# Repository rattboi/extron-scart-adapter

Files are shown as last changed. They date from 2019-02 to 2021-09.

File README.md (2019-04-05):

Extron Scart Adapter projects
=============================

Extron Input Adapter
--------------------

[Extron-Input README](extron-input/README.md)

This board should plug into an extron crosspoint input, and has the following features:

1) Female Scart input
1) JST header to Phoenix adapter (cheap)
1) Sense header to determine if connected cable is "active"
1) Selectable LM1881 Sync Stripper for sync on composite video / sync on luma

Extron Output Adapter
--------------------

[Extron-Output README](extron-output/README.md)

This board should plug into an extron crosspoint output, and has the following features:

1) Female Scart output
1) JST header to Phoenix adapter (cheap)
1) Selectable termination resistor for 75 ohm or TTL level sync output

Extron SCART Autoswitcher
-------------------------

[Autoswitcher README](esp32-switcher/README.md)

This board plugs into the serial port on an Extron crosspoint, and works together with the input cards to determine which input has be most-recently powered on, and automatically switches to that input.

Simple Scart Adapter (DEPRECATED)
---------------------------------

This board was my first attempt, and it turned out to not be workable. I'm leaving it for posterity, but you shouldn't use it.
The spacing is way off for a Crosspoint. I based the measurements on an Extron System 5CR Plus, which has narrower spacing between BNC connectors.

License
-------

These projects are licensed under CERN Open Hardware Licence v1.2

This is a work-in-progress as well, as I believe I'm missing the attribution on the boards. My intent is to license them properly.

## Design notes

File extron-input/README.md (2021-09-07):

Extron SCART Input adapter
==========================

The Extron SCART Input adapters are designed to be inserted into an Extron Crosspoint input vertically, using BNC->RCA male adapters to mate with the adapter card's RCA female jacks. There are two supported BNC spacings, one that is looser (older Extrons) and one that is tighter (newer Extrons). When you assemble your card, you use the correct RCA spacing to support your Extron. The looser spacing is labeled RED1/GREEN/BLUE1/SYNC1, while the tighter spacing is labeled RED2/GREEN/BLUE2/SYNC2. You'll notice that GREEN is shared between the two spacings.

Below, you will notice that there is a design for a 'top' card and a 'bottom' card. This was required in order to get the cards close enough together horizontally (from the perspective of the Extron). The SCART heads are large and for the newer Extron spacing, the BNC spacing is just too tight to have the SCART heads stack. Therefore, you should plan to make both 'top' and 'bottom' cards, and alternate them. I use plastic standoffs to group 3-4 boards together. For the newer Extrons, I found that alternating 15mm and 16mm standoffs gave a perfect fit. Anothe alternative would be to just pair up a top and bottom board, and use either 15mm or 16mm. The error builds when you try to create a larger matrix, so you shouldn't have any problem if you make smaller matrices.

Features
========

The Extron input cards have optional sync strippers that are togglable via a switch that is labeled on the PCB. The lm1881 sync stripper is powered by the SCART cable's pin 8 (switch pin). The SCART standard says that this should be carrying 5v-12v. Anywhere in that range works fine to power the lm1881.

Also, there is a small custom circuit to determine if the console is powered on, via the switch pin on the SCART connector. This can be paired with the [autoswitcher](../esp32-switcher) to automatically switch the extron input to match the last powered-on device. This circuit takes 5-12V and lowers it down to 2.5-3.3V, which is low enough to be a simple digital 'on' signal to the [autoswitcher](../esp32-switcher) board.

PCB Renders
===========

## Front

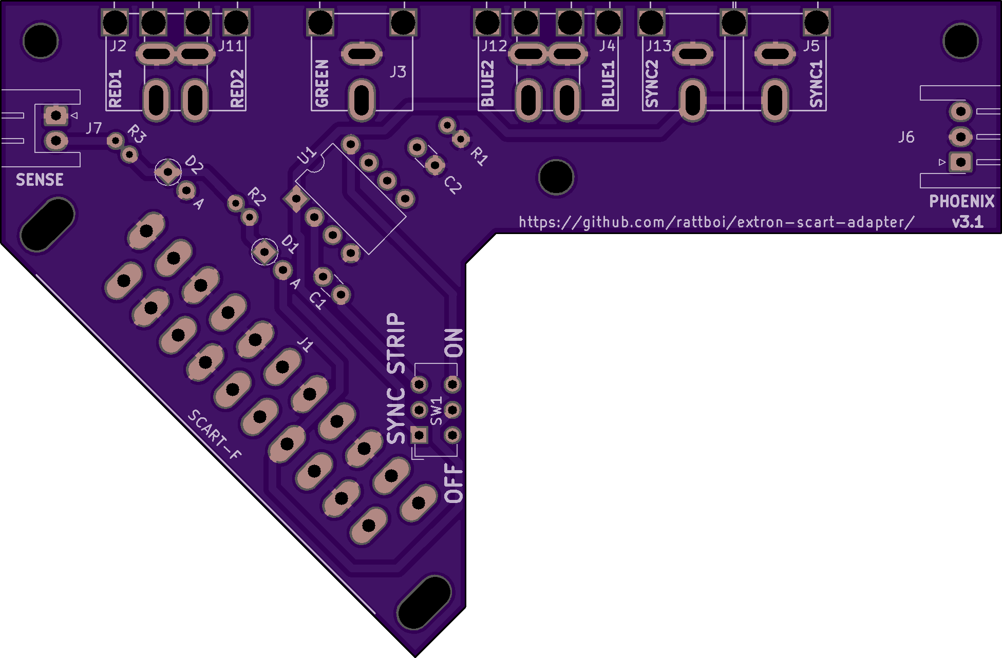
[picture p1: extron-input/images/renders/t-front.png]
Front Render

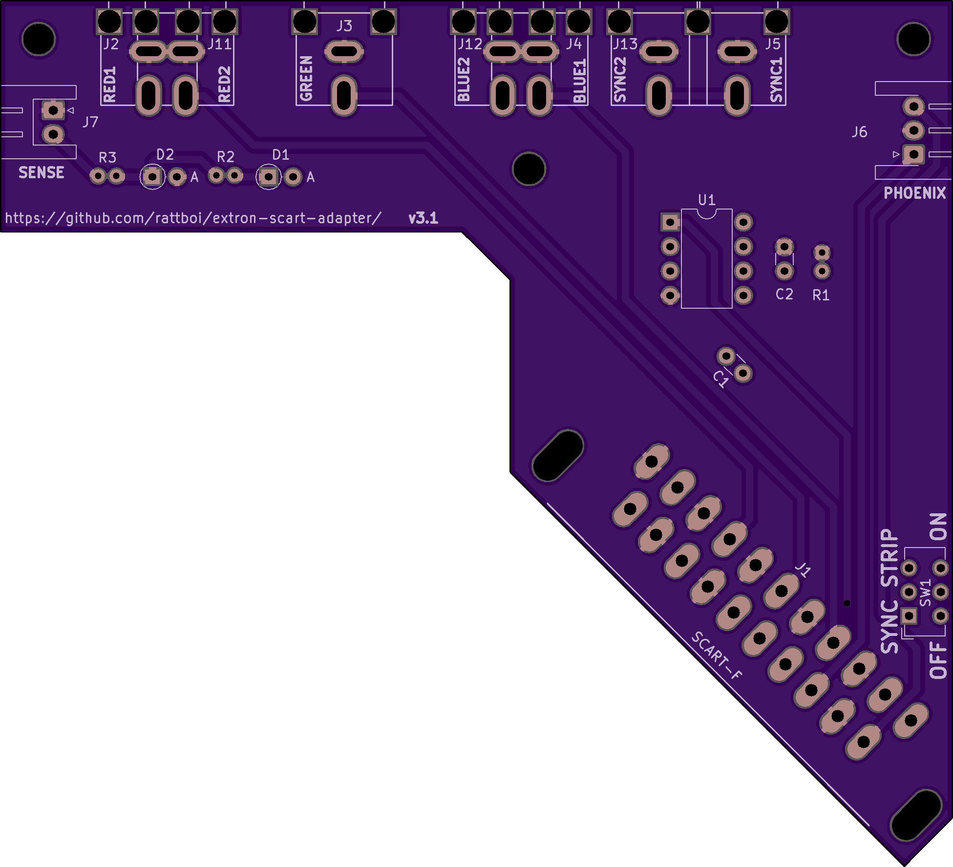
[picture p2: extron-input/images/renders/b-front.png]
Front Render


## Back

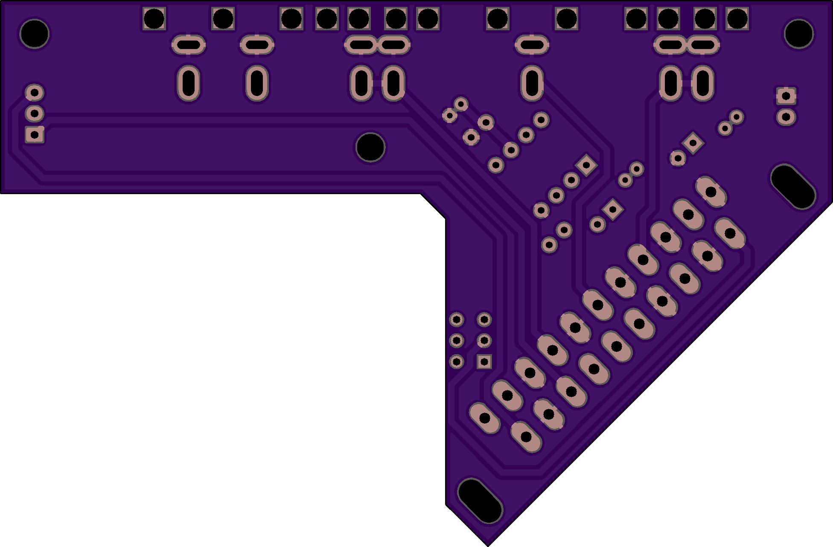
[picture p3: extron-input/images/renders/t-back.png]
Back Render

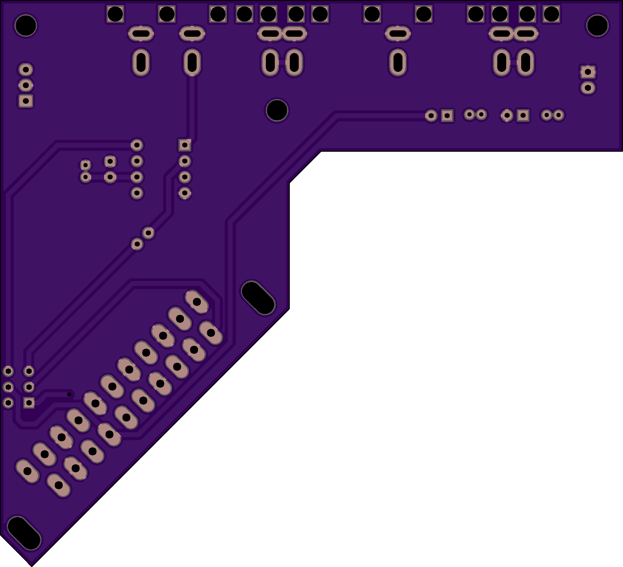
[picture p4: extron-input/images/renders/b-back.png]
Back Render


3D Renders
==========

## Top

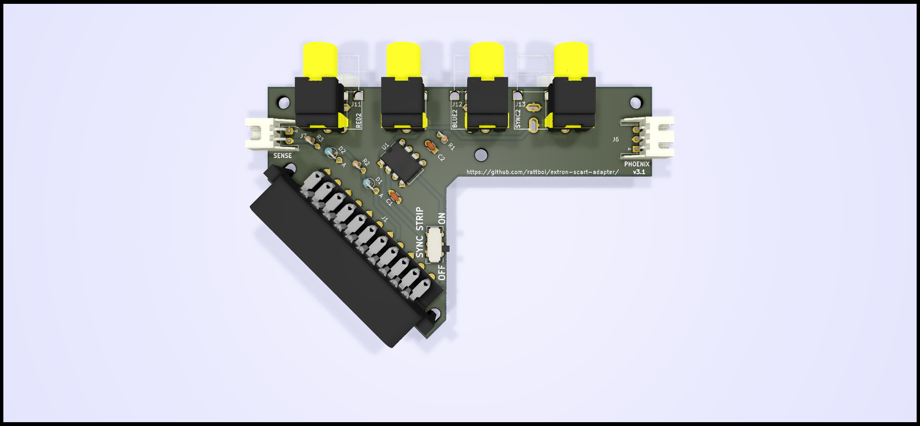
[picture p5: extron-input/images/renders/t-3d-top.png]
Top Render

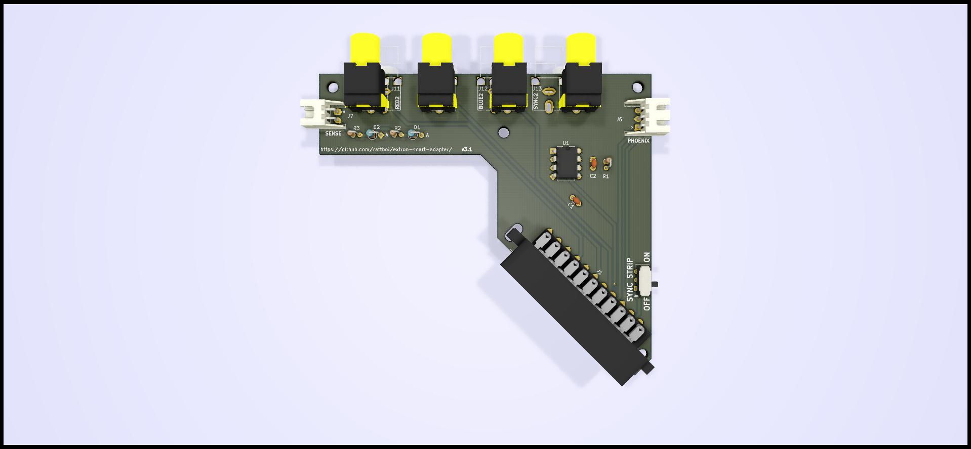
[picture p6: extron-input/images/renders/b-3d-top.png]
Top Render


## Front

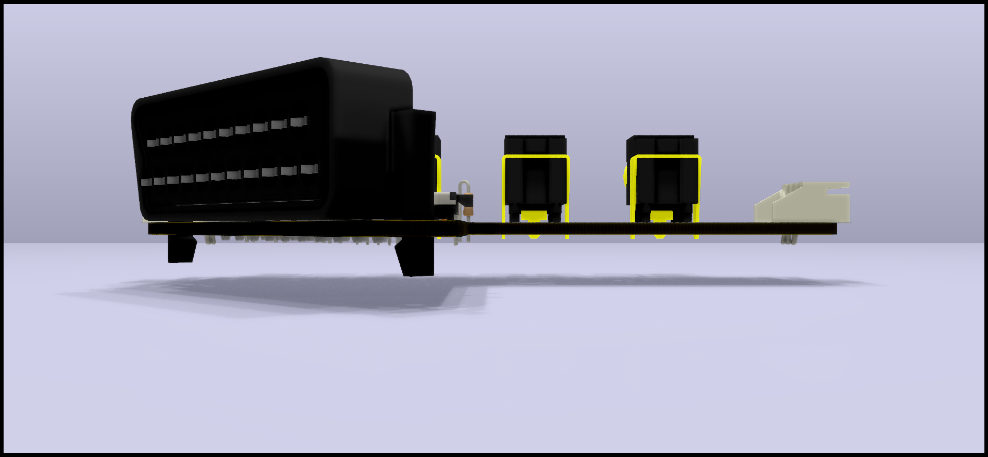
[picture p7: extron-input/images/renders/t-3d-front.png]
Front Render

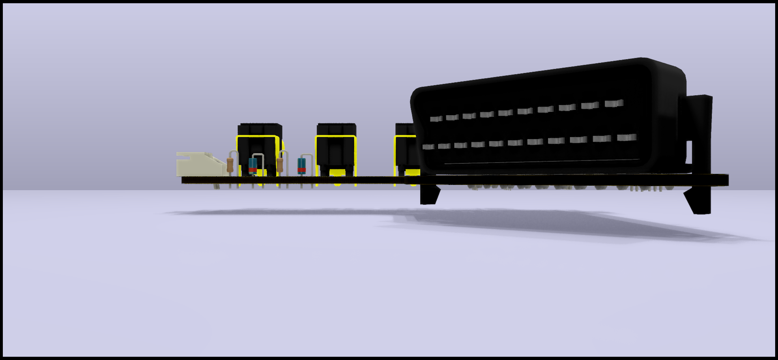
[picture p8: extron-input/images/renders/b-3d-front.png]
Front Render


## Side

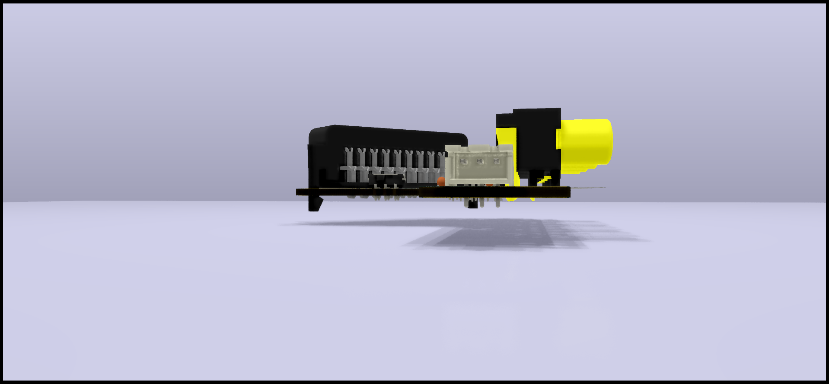
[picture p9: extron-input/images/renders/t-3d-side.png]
Side Render

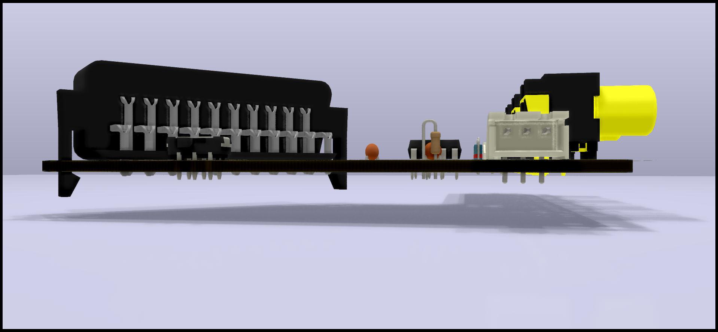
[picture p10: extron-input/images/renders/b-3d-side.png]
Side Render


Assembled Cards
===============

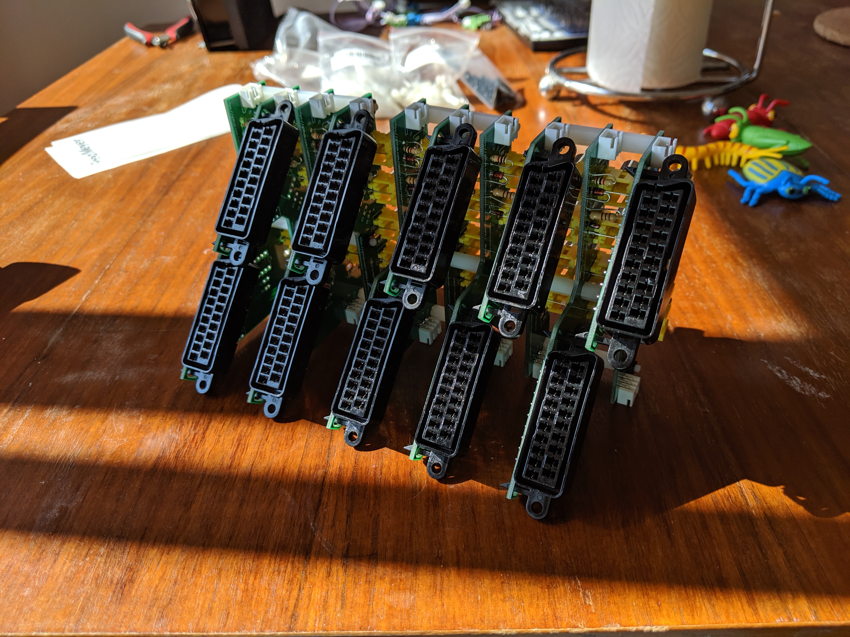
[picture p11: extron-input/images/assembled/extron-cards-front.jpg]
Front

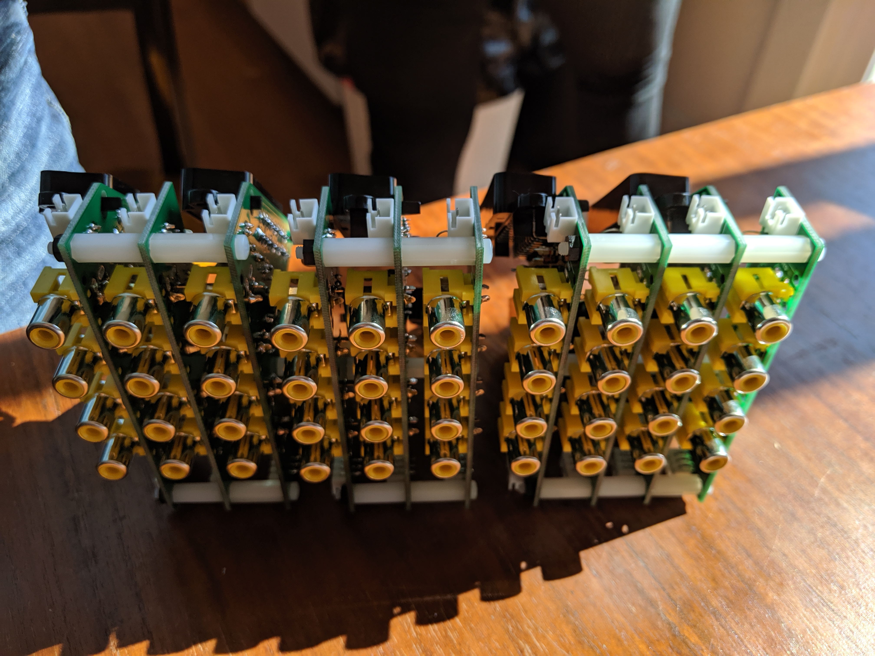
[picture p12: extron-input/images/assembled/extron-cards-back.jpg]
Back

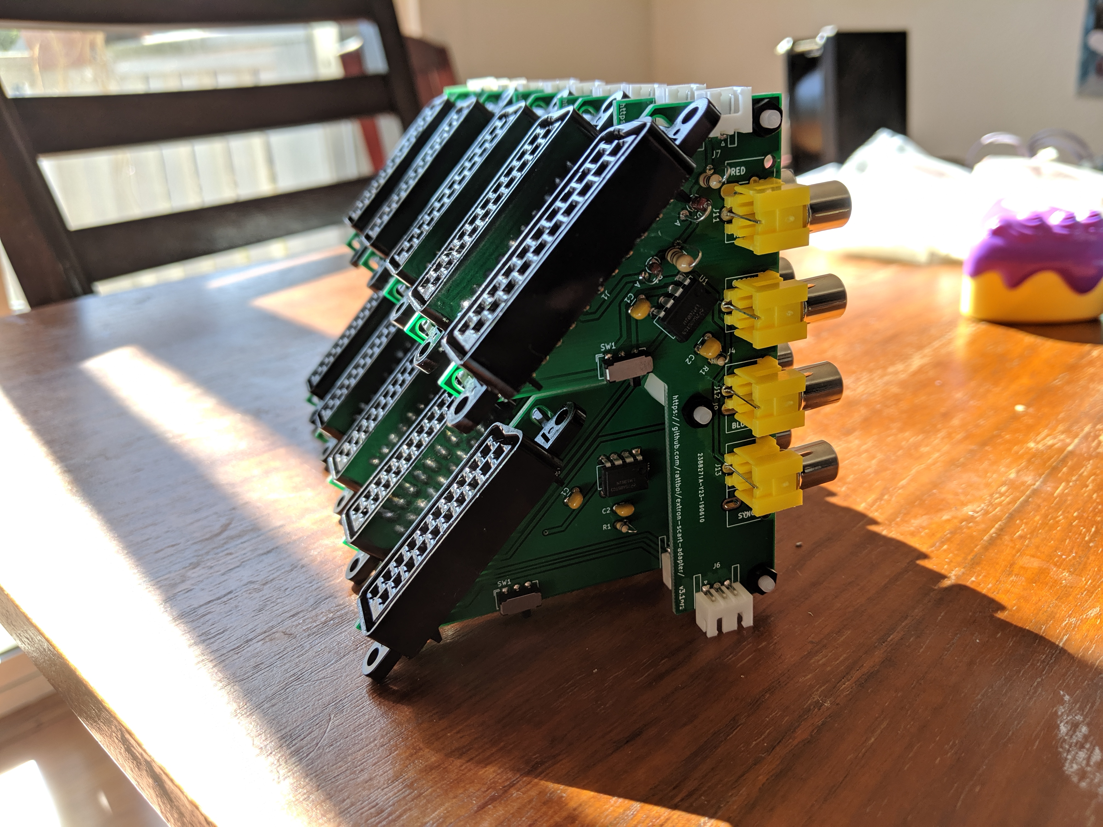
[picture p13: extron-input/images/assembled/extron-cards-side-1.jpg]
Side 1

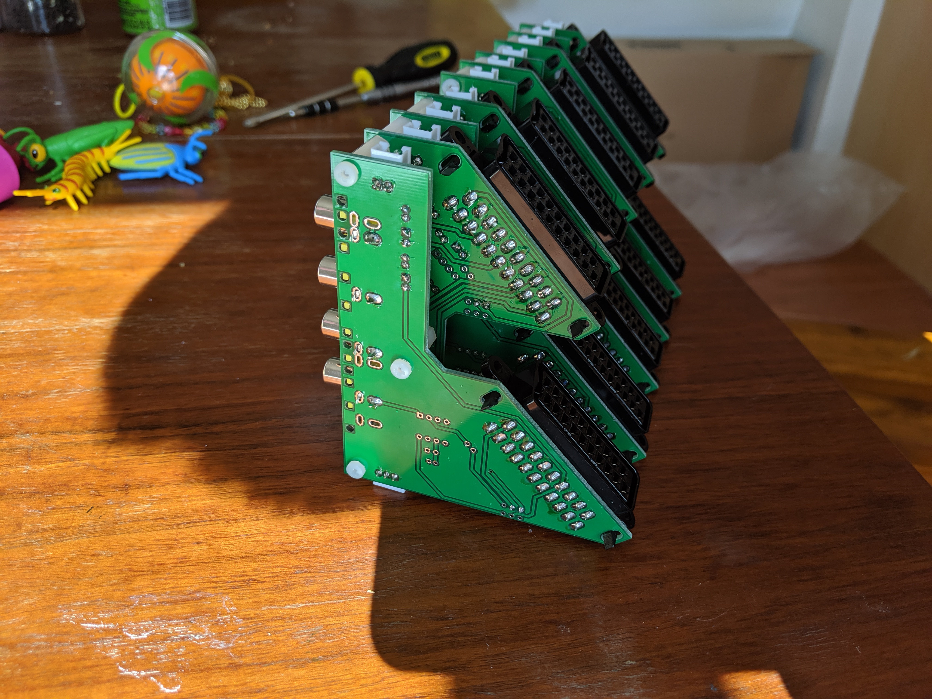
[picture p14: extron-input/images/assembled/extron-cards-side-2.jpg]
Side 2


Others
======

Back of Extron, prepared for cards
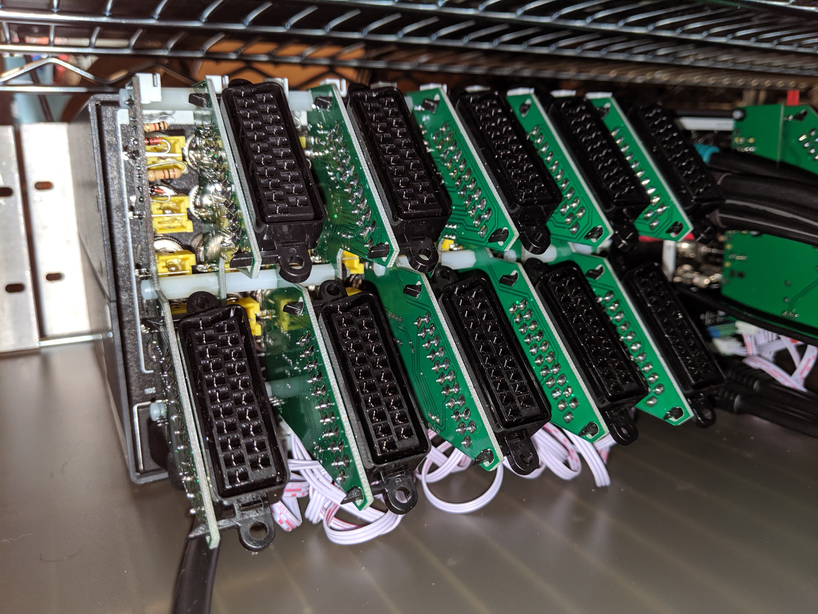
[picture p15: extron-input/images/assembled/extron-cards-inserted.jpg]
Cards inserted, no SCART cables

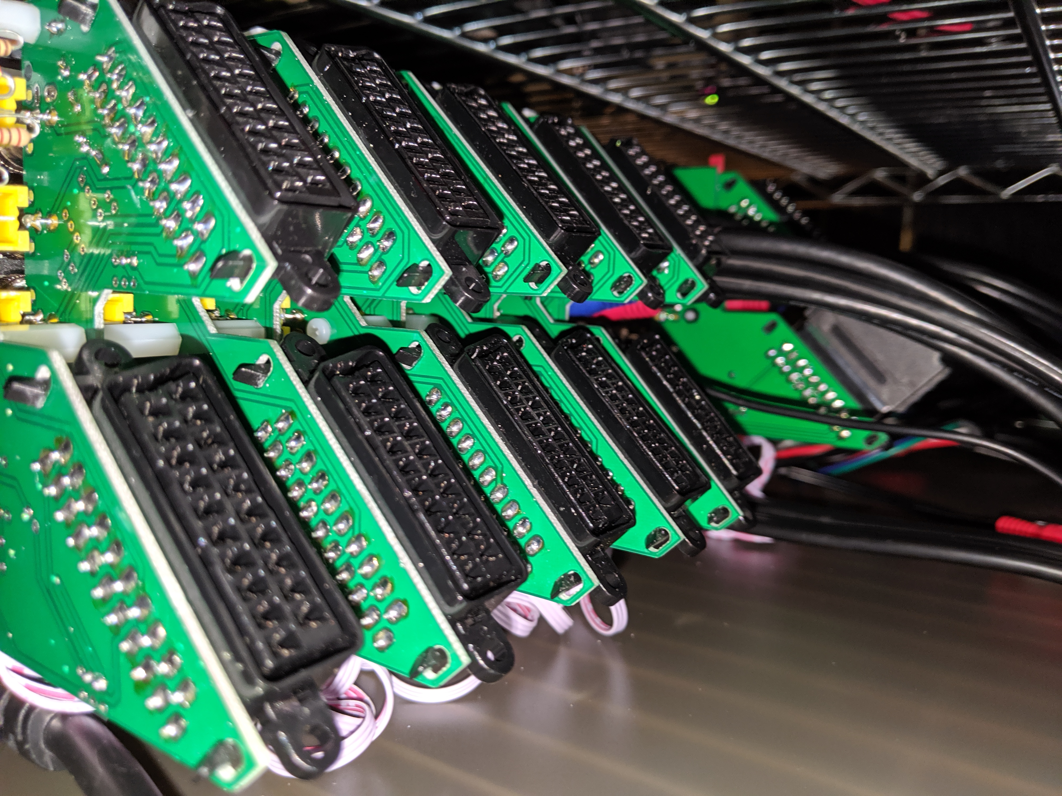
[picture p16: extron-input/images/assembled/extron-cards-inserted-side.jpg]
Cards inserted, no SCART cables (side)

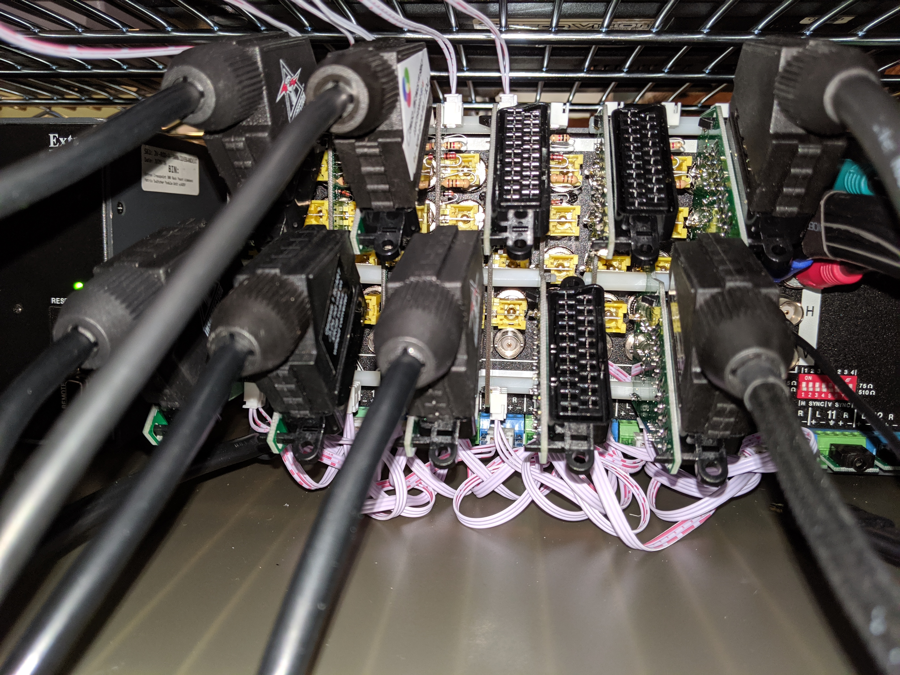
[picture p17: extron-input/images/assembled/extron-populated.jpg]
Cards inserted, with SCART cables


BOM
===========
| Item | Qty | Reference(s) | Value | Footprint | Datasheet |
|---|-----|---|---|---|---|
| 1 | 2 | C1, C2 | 0.1uF | Capacitor_THT:C_Disc_D3.0mm W1.6mm_P2.50mm | https://lcsc.com/product-detail/Multilayer-Ceramic-Capacitors-MLCC-Leaded_100nF-104-20-100V_C154503.html |
| 2 | 1 | D1 | 1N4148 | Diode_THT:D_DO-35_SOD27 P2.54mm_Vertical_AnodeUp | https://lcsc.com/product-detail/Switching-Diode_1N4148_C14516.html |
| 3 | 1 | D2 | 1N4728A | Diode_THT:D_DO-35_SOD27 P2.54mm_Vertical_AnodeUp,~ | https://lcsc.com/product-detail/Zener-Diodes_ON-Semicon_1N4728A_ON-Semicon-ON-1N4728A_C140852.html |
| 4 | 1 | J1 | SCART-F | extron-input:SCART_F_RA, ~ | https://console5.com/store/female-scart-jp21-through-hole-pcb-mount-21-pin-connector-right-angle.html |
| 5 | 1 | J2/J11 | RED | extron-input:rca_boom, ~ | https://lcsc.com/product-detail/AV-Connectors_AV-5_C18080.html |
| 6 | 1 | J3 | GREEN | extron-input:rca_boom, ~ | https://lcsc.com/product-detail/AV-Connectors_AV-5_C18080.html |
| 7 | 1 | J4/J12 | BLUE | extron-input:rca_boom, ~ | https://lcsc.com/product-detail/AV-Connectors_AV-5_C18080.html |
| 8 | 1 | J5/J13 | SYNC | extron-input:rca_boom, ~ | https://lcsc.com/product-detail/AV-Connectors_AV-5_C18080.html |
| 9 | 1 | J6 | PHOENIX | Connector_JST:JST_XH_S03B XH-A_1x03_P2.50mm_Horizontal,~ | https://lcsc.com/product-detail/XH-Connectors_JST_S3B-XH-A-LF-SN_XHsocket-1-3P-Curved-needle-pitch2-5mm_C157928.html |
| 10 | 1 | J7 | SENSE | Connector_JST:JST_XH_S02B XH-A_1x02_P2.50mm_Horizontal,~ | https://lcsc.com/product-detail/XH-Connectors_JST_S2B-XH-A-LF-SN_XHsocket-1-2P-Curved-needle-pitch2-5mm_C157931.html |
| 11 | 4 | J8, J9, J10, J11 | Conn_01x01 | MountingHole:MountingHole_3.2mm_M3 | N/A |
| 12 | 1 | R1 | 680KΩ | Resistor_THT:R_Axial_DIN0204 L3.6mm_D1.6mm_P1.90mm_Vertical | https://lcsc.com/product-detail/Others_FlyWin-CR1-8W-5-680K-OTB5_C337028.html |
| 13 | 1 | R2 | 100Ω | Resistor_THT:R_Axial_DIN0204 L3.6mm_D1.6mm_P1.90mm_Vertical | https://www.lcsc.com/product-detail/Through-Hole-Resistors_CCO-Chian-Chia-Elec-CF1-4W-100-5-T52_C120031.html |
| 14 | 1 | R3 | 1KΩ | Resistor_THT:R_Axial_DIN0204 L3.6mm_D1.6mm_P1.90mm_Vertical | https://lcsc.com/product-detail/Carbon-Film-Resistors_1KR-102-5_C120055.html |
| 15 | 1 | SW1 | SW_DPDT_x2 | Button_Switch_THT:SW_CuK JS202011AQN_DPDT_Angled, | https://lcsc.com/product-detail/Toggle-Switches_C-K_JS202011AQN_C-K-JS202011AQN_C221662.html |
| 16 | 1 | U1 | LM1881 | Package_DIP:DIP-8_W7.62mm, | https://www.ti.com/store/ti/en/p/product/?p=LM1881N/NOPB

LCSC     Sub-total: __$14.94__ for everything for 10x boards (plus lots of spare parts)

Console5 Sub-total: __$14.90__ for RA Female SCART connectors

TI       Sub-total: __$28.40__ for LM1881n 

BOM Total for 10x boards: __$58.40__ plus Console5/TI shipping

BOM Total with shipping: __~$70__

You'll want 5x of the top boards and 5x of the bottom boards
PCBs: __$4 for 5__ top, __$4 for 5__ bottom, plus $6 for slower shipping = __$14__

Cost for 10 boards, all parts: $70+14 = $84 = __$8.40__ each

Other Supporting Parts 
======================

Phoenix adapter (for audio)
---------------------------

I've respun db_electronics' Phoenix RCA plug board to use JST headers: https://github.com/rattboi/phoenix-audio-adapter-kicad/tree/jst-xh/

$5 for 10x more boards on JLCPCB order, and $0.89 for JST headers

__$5.89__ for 10x populated boards = __$0.59 each__

JST cables (connect input audio to phoenix board)
----------
https://www.amazon.com/gp/product/B07HRMWVK9/

__$8 for 10__(need to find a better source)

BNC M to RCA M Plug Adapters
---------------
https://www.amazon.com/gp/product/B005C2KA88/

$5.39 for 10

__$21.56 for 40__ (4x per board, 10 boards)

Alternative: 

https://www.amazon.com/gp/product/B01H1A4QAQ/

$6.42 for 10

$25.68 for 40

10x board Total
===============
10x board + phoenix + cables + adapters: $84 + $6 + $8 + $22 = __~$120__

__$12 each, all parts, shipped__

10x boards Stripped-down 
------------------------

If you were to remove the optional components (no sync stripper, no sense circuit), you can get the price down further

Removing switch + lm1881 and passives for lm1881 + passives for sense circuit + sense connector: 

LCSC     Sub-total: $7.06

Console5 Sub-total: $14.90 for SCART connectors

BOM Total with shipping: $7.06 + $14.90 + $5 = $27

PCBS are the same, so $14 for 10x boards shipped

The rest of the parts are the same

10x board + phoenix + cables + adapters: $41 + $3 + $8 + $23 = __~$75__

__$7.50 each, stripped-down, shipped__

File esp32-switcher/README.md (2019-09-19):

Extron SCART Autoswitcher
=========================

This board, in conjunction with a HiLetGo ESP-E32 development board, can be used to sense input changes from the Extron Input adapters, and use that information to automatically switch to the most recently turned-on input.

Each input board has a sense port, which you connect to the autoswitch board via a JST XH cable. The board then plugs into your extron either via straight-through M-F serial cable (not null modem), or by directly mounting the board onto the port. The ESP32 also needs external power, which can be supplied by any 5V USB charger that you may have laying around.

PCB
===

3D Renders
==========
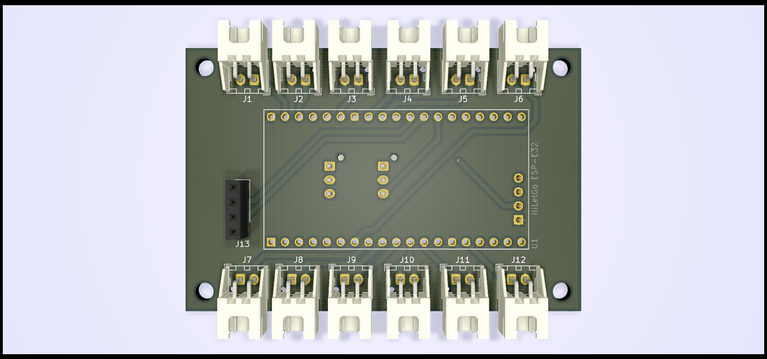
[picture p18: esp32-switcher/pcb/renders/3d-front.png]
Front Render

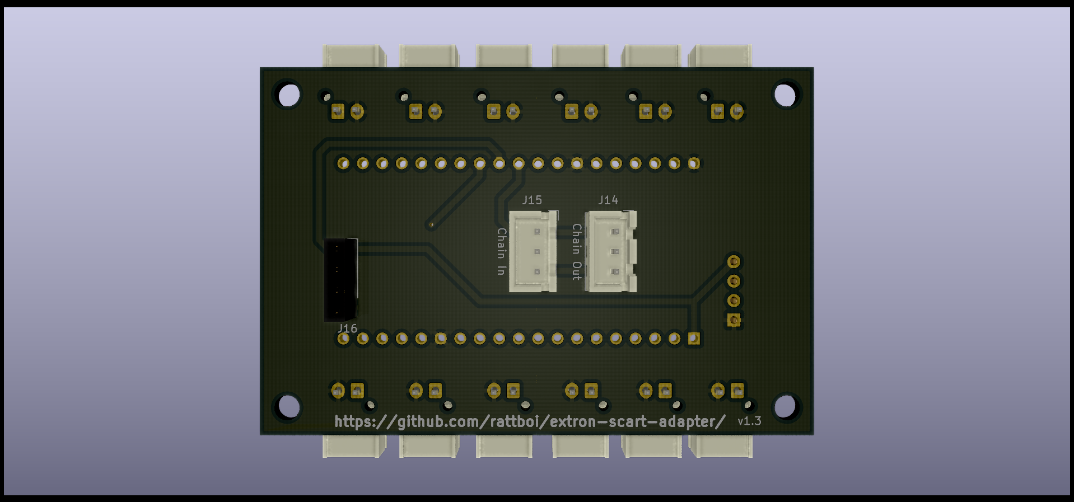
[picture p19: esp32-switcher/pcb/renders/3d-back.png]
Back Render


PCB Renders
===========

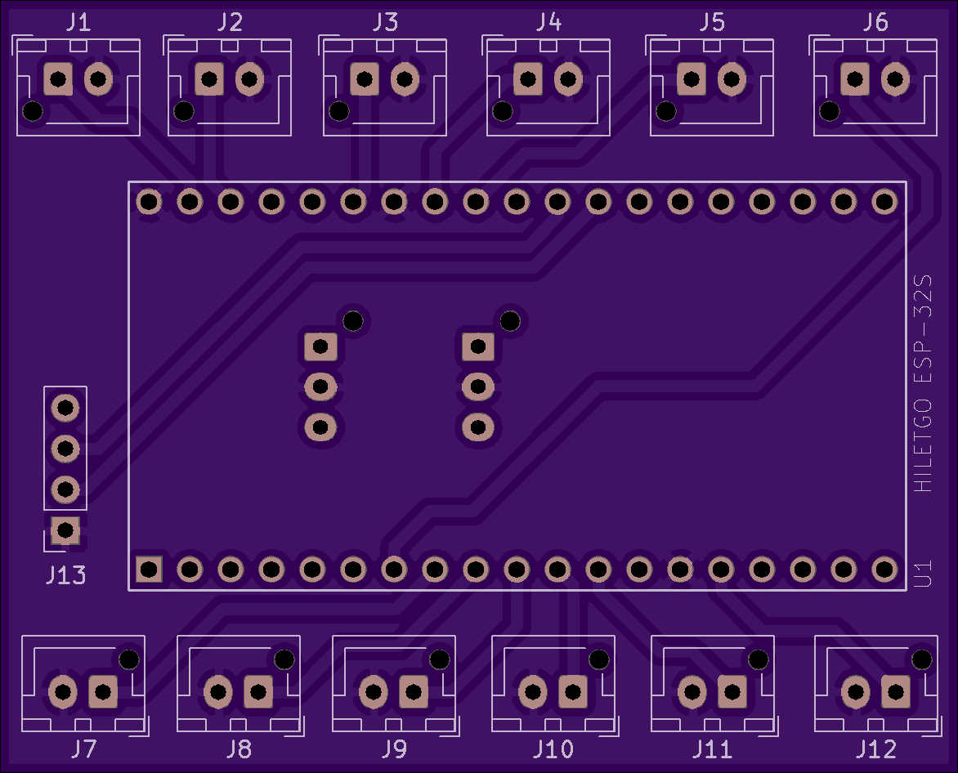
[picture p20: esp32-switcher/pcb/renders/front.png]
Front Render

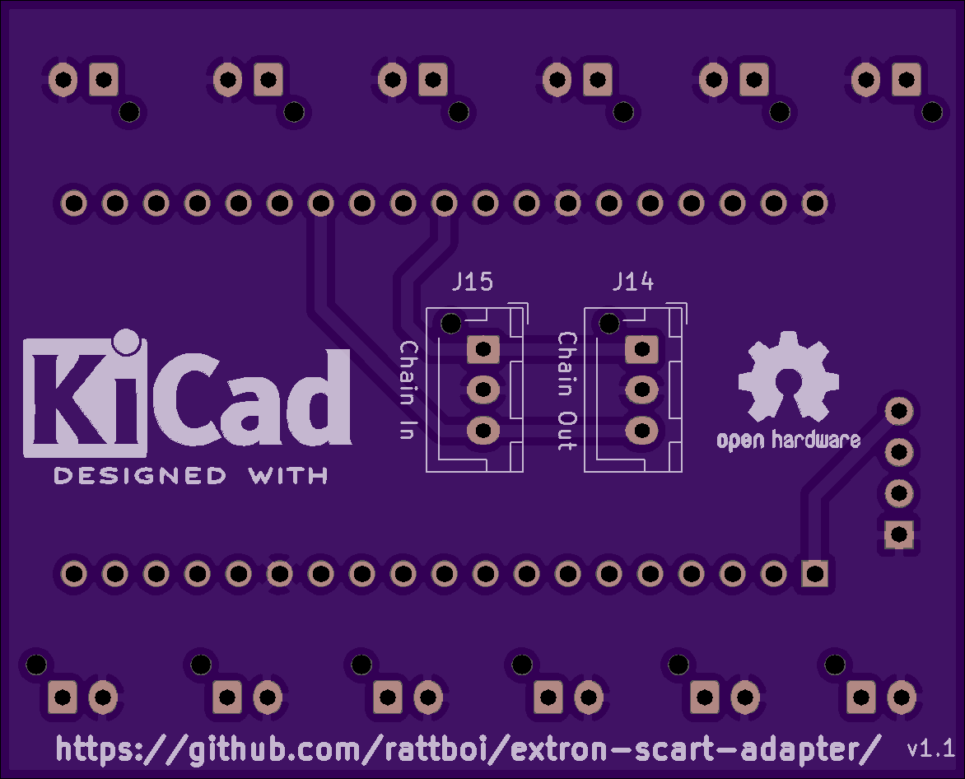
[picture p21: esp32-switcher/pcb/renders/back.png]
Back Render


BOM
===========
| Item  | Qty | Reference(s) | Value | Footprint | Datasheet |
|---|-----|---|---|---|---|
| 1 | 1 | U1 | ESP32 | hiletgo-e32:HILETGO-E32 |  https://www.amazon.com/gp/product/B0718T232Z/ref=ppx_yo_dt_b_search_asin_title?ie=UTF8&psc=1 |
| 2 | 1 | J13/J16 | RS232 | Connector_PinSocket_2.54mm:PinSocket_1x04_P2.54mm_Vertical  |  https://www.amazon.com/gp/product/B00OPU2QJ4/ref=ppx_yo_dt_b_asin_title_o02_s00?ie=UTF8&psc=1 |
| 3 |  14 | J1-12,14,15 | JST-XH RA  | Connector_JST:JST_XH_B2B-XH-AM_1x02_P2.50mm_Vertical | |

Notes:
* You only need one RS232 TTL Converter. There's two spots (J13 or J16) on the board to place it, depending on what orientation you want your switchboard to be.
* You can skip J14/J15 for now. They are WIP to chain together switchboards for cascading multiple Extrons
* If you don't want the ESP32 to be permanently soldered to the switchboard, you can use pin header for the two rows of pins where the ESP32 plugs in.
* I would recommend directly soldering the RS232 in place for stability, but you could use pin header there as well.

Code
====

The code for the autoswitcher is currently in micropython. The basic steps involved are as follows to get the board going.

1) Install any driver you may need for the usb->serial built into the ESP32. This is the CP2102 driver, and necessary for Windows and macOS. Linux comes with this driver pre-installed.

2) Plug the ESP32 into your computer, and find the serial device.
  This is straightforward in Linux/macOS, as it appears as /dev/ttyUSB0 or something close to that. I'm not actually sure what this looks like in windows.

3) Install the following programs to interact with the ESP32: esptool.py and ampy.
  esptool.py will allow you to flash micropython onto your ESP32
  ampy will allow you to move the boot code from this repo onto your ESP32 to be executed by micropython

4) Install micropython, some current revision.
  I'm not going to go through all the steps for this, but on Linux it looks something like `sudo esptool --chip esp32 -p /dev/ttyUSB0 write_flash -z 0x1000 ~/Downloads/esp32-20190328-v1.10-243-g92149c8a7.bin`
  `
5) Move the boot code over after micropython is installed
  `ampy -p /dev/ttyUSB0 put code/boot.py`

You're done now. Plug everything in. J1 -> Input 1, J2 -> Input 2, etc.

Congrats, now you have autoswitching power!

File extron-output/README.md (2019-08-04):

Extron SCART Output Adapter
==========================

PCB Renders
===========

## Front

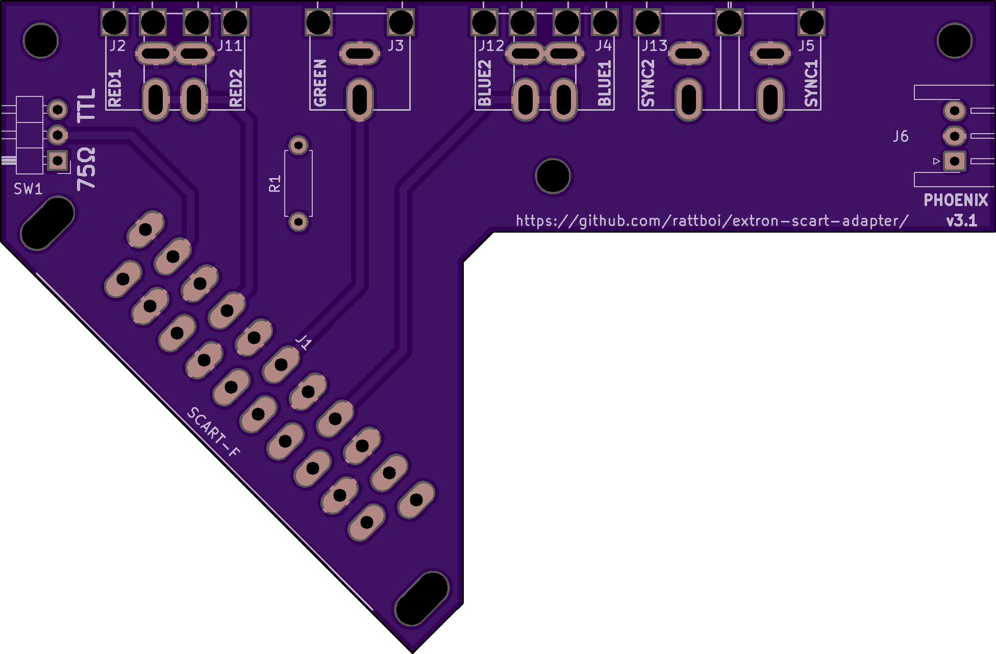
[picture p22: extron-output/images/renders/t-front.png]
Front Render

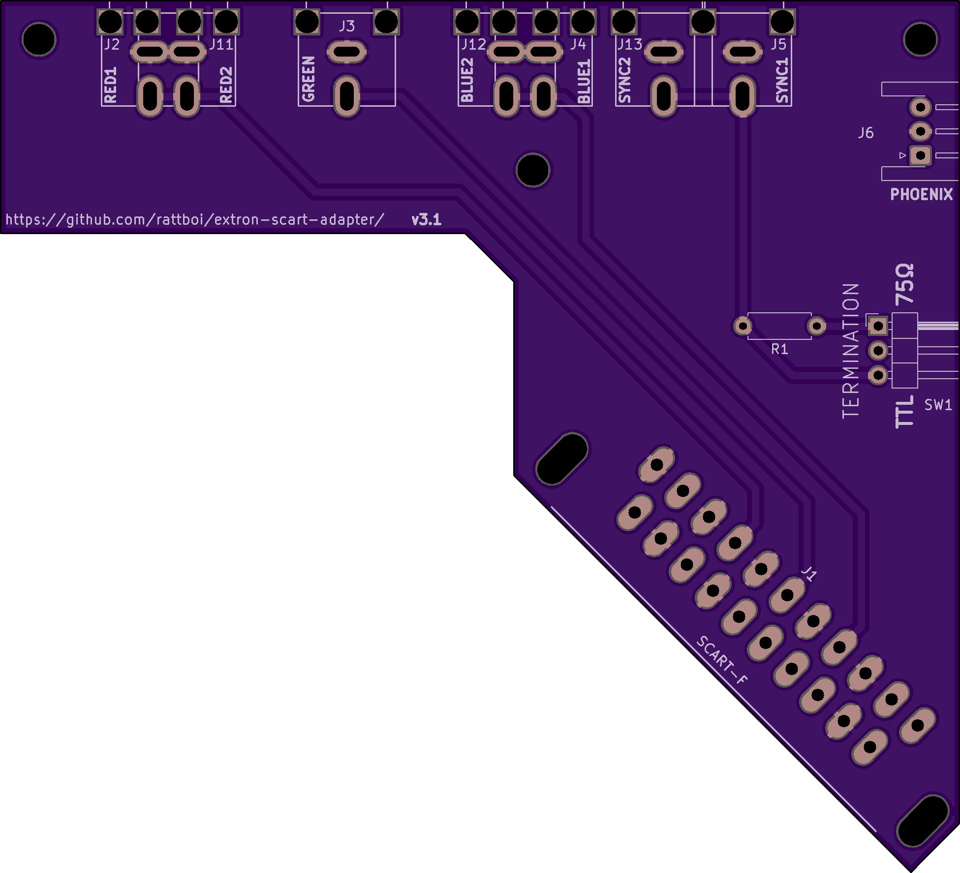
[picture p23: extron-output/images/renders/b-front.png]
Front Render


## Back

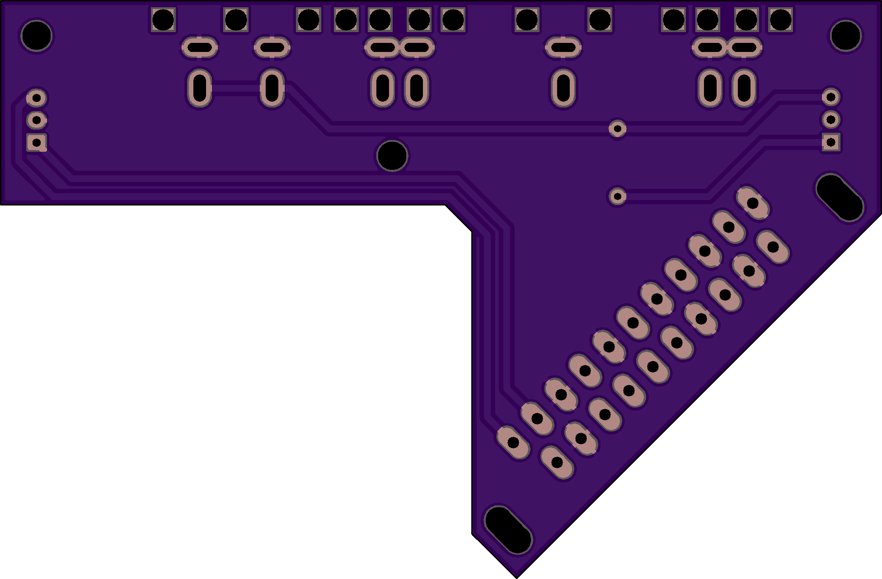
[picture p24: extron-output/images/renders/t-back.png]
Back Render

Back Render

3D Renders
==========

## Top

Top Render
Top Render

## Front

Front Render
Front Render

## Side

Side Render
Side Render

BOM 
===

| Item | Qty | Reference(s) | Value | Footprint | Datasheet |
|---|-----|---|---|---|---|
| 1 | 1 | J1 | SCART-F | extron-input:SCART_F_RA, ~ | https://console5.com/store/female-scart-jp21-through-hole-pcb-mount-21-pin-connector-right-angle.html |
| 2 | 1 | J2/J11 | RED | extron-input:rca_boom, ~ | https://lcsc.com/product-detail/AV-Connectors_AV-5_C18080.html |
| 3 | 1 | J3 | GREEN | extron-input:rca_boom, ~ | https://lcsc.com/product-detail/AV-Connectors_AV-5_C18080.html |
| 4 | 1 | J4/J12 | BLUE | extron-input:rca_boom, ~ | https://lcsc.com/product-detail/AV-Connectors_AV-5_C18080.html |
| 5 | 1 | J5/J13 | SYNC | extron-input:rca_boom, ~ | https://lcsc.com/product-detail/AV-Connectors_AV-5_C18080.html |
| 6 | 1 | R1 | 470 | R_Axial_DIN0204_L3.6mm D1.6mm_P1.90mm_Vertical | https://lcsc.com/product-detail/Metal-Film-Resistor-TH_470R-471-5_C176518.html |
| 7 | 1 | J6 | PHOENIX | Connector_JST:JST_XH_S03B XH-A_1x03_P2.50mm_Horizontal,~ | https://lcsc.com/product-detail/Wire-To-Board-Wire-To-Wire-Connector_JST-Sales-America_S3B-XH-A-LF-SN_JST-Sales-America-S3B-XH-A-LF-SN_C157928.html |
| 8 | 1 | SW1 | CSYNC | 3x1 Pin Header | (fill me in) |

LCSC     Sub-total: __$6.76__ for everything for 10x boards (plus lots of spare parts)
Console5 Sub-total: __$14.90__ for RA Female SCART connectors
BOM Total: __$21.66__ for 10x boards

You'll want 5x of the top boards and 5x of the bottom boards
PCBs: __$4 for 5__ top, __$4 for 5__ bottom, plus $6 for slower shipping = __$14__

Total board Costs for 10: $21.66+14 = $35.66 =  $3.57 each (pretty cheap)

Other Supporting Parts 
======================

Phoenix adapter (for audio)
---------------------------

I've respun db_electronics' Phoenix RCA plug board to use JST headers: https://github.com/rattboi/phoenix-audio-adapter-kicad/tree/jst-xh/

$5 for 10x more boards on JLCPCB order, and $0.89 for JST headers

__$5.89__ for 10x populated boards = __$0.59 each__

JST cables (connect input audio to phoenix board)
----------
https://www.amazon.com/gp/product/B07HRMWVK9/

__$8 for 10__(need to find a better source)

BNC M to RCA M Plug Adapters
---------------
https://www.amazon.com/gp/product/B005C2KA88/

$5.39 for 10

__$21.56 for 40__ (4x per board, 10 boards)

Alternative: 

https://www.amazon.com/gp/product/B01H1A4QAQ/

$6.42 for 10

$25.68 for 40

10x board Total
===============
10x board + phoenix + cables + adapters: $36 + $6 + $8 + $22 = __~$72__

__$7.20 each, all parts, shipped__

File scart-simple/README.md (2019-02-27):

SPACING IS WRONG - DONT USE
===========================

This is just here for posterity. I may remove it later

Idea: Design a PCB that can mount directly to an extron 4x BNC input, on the cheap, and without cables (mostly).

To make this possible, use the following:

1) 4x pcb-mountable RCA female connectors (R, G, B, H)  
https://www.digikey.com/product-detail/en/cui-inc/RCJ-021/CP-1406-ND/408493

2) 4x rca male to BNC male adapters
https://www.amazon.com/Hosyl-Male-Plug-Adapters-Pack/dp/B01H1A4QAQ/

3) A pcb-mountable female SCART connector
https://www.mouser.com/ProductDetail/Kycon/K-SCARTX-024?qs=BXFTyIlnqNt1WE8CDO1Pgg%3D%3D

4) A PCB with SCART connector on one side, and the RCA female connectors (very accurately placed) on the other side
Front Render
Back Render

Put adapters down your BNC input line on the extron so you have 4x rca male instead. 

Plug this PCB's 4x rca female plugs into those 4x rca male jacks.

Now you have a SCART input!

Based on some napkin math, it'd be about $10/input for this configuration. It's closer to $12/input when adding in phoenix adapters for audio.

Future ideas:

Extron gear requires csync, so probably need an option to add a sync stripper circuit for whatever is on SCART pin 20.

Not sure the best way to do this, but if you had sense lines to each board going to a raspberry pi, you could auto-switch using the RS-232 on the extron. One can dream...

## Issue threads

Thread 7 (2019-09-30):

KiCad Version Issue

qwertymodo, 2019-09-30:
It seems like the KiCad files were created using a nightly build from 5/16/2019.  This causes issues trying to open the files using the stable release versions, as even versions that are newer than 5/16/2019, such as the current v5.1.4, released 8/4/2019, complain that they can't open the files because they were created with a more recent version than the one you're running.  This seems like a bug in KiCad, but I figured it was worth reporting here as well.

rattboi, 2020-01-31:
Sorry about that!

Fixed with https://github.com/rattboi/extron-scart-adapter/pull/8

Closed 2020-01-31.

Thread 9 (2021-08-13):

Problem with autoswitch

pattonthompson, 2021-08-13:
I’ve tried two different extrons.  84 series and 300 series.  Everything works perfectly manually switching, 8 consoles in, 1 output.  All scart.  I’ve flashed the custom boot.py to the root of the esp32.  Autoswitching is not working.  Have tried factory resetting both extrons.  Is there a step I’m missing?  Any help greatly appreciated.

rattboi, 2021-08-16:
https://github.com/rattboi/extron-scart-adapter/tree/master/esp32-switcher#code

I know these steps are wishy-washy. Just gotta verify you did in fact follow these steps and have micropython installed onto your esp32 and running this code.

pattonthompson, 2021-08-18:
I appreciate your reply.  the soldering part wasn't bad but I'm new to micropython.  I think this confirms I have the code in the right spot on the ESP32 but I could be wrong.  See attached screenshot.
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

rattboi, 2021-08-18:
Indeed, I would agree that you have micropython and the code loaded up.

Further debugging ideas:

1. take one of the JST 2-pin cables that would go to the auto-switcher and cut and wire to multimeter. Plug into the Scart Input adapter card. Make sure you see a signal change when you turn the console on and off from the adapter card.

2. Do direct connection from your PC to the extron using a regular USB->RS232 adapter. Configure for 9600 baud, 8 data bits, no parity bit, 1 stop bit. You should be able to switch channels by typing "1*1!", "2*2!", "1*2!". The format is "<input>*<output>!"

3. Get some pictures of your setup and attach them and I'll see if I see anything odd.

4. Message me on discord at rattboi#7637, and I can try and work together with you on other ideas.

pattonthompson, 2021-09-01:
Sure enough got 5 volts on the scart cables.  I think I probably reversed the polarity of the diodes.  If that is correct it should be an easy fix.  Attached a close up of one of my input cards (I did them all the same way).

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

rattboi, 2021-09-01:
Components look like they're oriented correctly, but the soldering needs some work. I shouldn't be able to see the hole in R2 or D2, and I'd say R3 looks like a cold solder joint. I'd take another pass with each, and use some flux if you have some.

Then I'd take the input card, attach a console SCART, and check the voltage from point to point along the path. From ground to the right-hand side of D1 should by 5V. IIRC, it should be like 4.3V from ground to the left-hand side of D1. The goal is to have something ~3V or more at the 2-pin connector on the top of the input board.

rattboi, 2021-09-03:
Looking over this again, I see that the main mistake is mine. You have a 100k resistor in R2, and that's correct according to the BOM I have in the readme. Unfortunately, that was a mistake and it should be 100 ohms, not 100k ohms. I'll be fixing up the BOM today. The resistor code should be BROWN BLACK BROWN GOLD, for 100 ohms.

rattboi, 2021-09-07:
Fixed in the BOM. Really sorry about that.

Closing issue. Feel free to re-open if you have more problems.

pattonthompson, 2021-09-07:
Sounds good thank you.  I did confirm with my multimeter.  Ordered the 100
ohm resistors.  Awesome of you to provide such good support.

Patton

On Tue, Sep 7, 2021 at 12:46 PM Bradon Kanyid ***@***.***>
wrote:

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

pattonthompson, 2022-12-21:
Its been awhile but i came back to this.  Still having the same problem:  manual switching is perfect, autoswitch not working.  I replaced R2 for 100 ohm resistors on all the input cards.  Im getting ~2.75V on the input sensing JST wires.  Maybe this is not enough?  You mentioned it should be 3 volts or more?

I reflashed the esp 32 and replaced boot.py just to be sure and had same result as above - code seems to be executing.

I hooked up the extron to PC.  I have no idea how to input those commands you suggested.  I.e. trying to use a program in windows to communicate ascii commands, etc.   But I did find the extron software and that works in creating ties, etc.  I was able to change to 9600 baud.  I wasn’t able to definitively check or change 8 data bits, no parity bit, 1 stop bit.  That feature wasn’t in the very basic software I could find.  Those are allegedly the factory setting and I have done several factory resets on the extron.  I forget what the exact setting is called but i have the extron set to “lock mode 1”, so front panel inputs / changes are not possible but theoretically should still be able to make changes through rs232 (kids what can i say🤣).

I dont know if this means anything but with the ttl rs232 connector unplugged, console 1 powered on and manually outputting to output one I get a little over 5V on the TxD pin compared to ground.  Using a standard iphone 5 volt charger to power esp32 board.

At this point I have no idea what I’m missing.  I feel like it could be something very dumb like a particular firmware for extron or esp 32.  Some Extron setting I’m missing.  Could be the 8 data bits, no parity bit, 1 stop bit issue.  Maybe my scart cables are not allowing enough voltage to get to board in the first place and thats why I get ~2.7 vots on the jst wires.  A lower resistor at R2 perhaps?  Do you wait to plug in the esp32 unti AFTER the extron is on?  I looked at some pics you had of the assembled switcher board on twitter everything appears to be the correct orientation.

As you can see I’m lost 🤷‍♂️.  The soldering / hardware stuff I understand more than the programming.  Any further help troubleshooting would be appreciated and might help someone else who’s stuck like me.

Closed 2021-09-07.

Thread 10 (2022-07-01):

Feeling mighty dumb - where's the board layout?

Numbski, 2022-07-01:
This is my first foray into KiCAD.  I've done a small amount in Eagle prior, and I got the schematic open in eeschema.  I swapped the Phonenix connector out for a normal 3.5mm jack - but when it came time to alter the board layout, I just cannot find it.  If I hit the board layout button in the UI, it says it doesn't exist and asks if I want to create it.

...am I blind?  I don't see it in your repo.  Just 3D renders and static images of the board, but no layout file.

Numbski, 2022-07-01:
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

rattboi, 2022-07-03:
The board schematic is the same, but there are two variant board layouts, for "top" and "bottom" boards. The .kicad_pcb files are within each of those subdirectories.

rattboi, 2022-07-03:
I am guessing you didn't see that the project file is also within top and bottom directories. You should open the .pro file with kicad and everything should be set up there.

Numbski, 2022-07-04:
Ah, okay.

Trying to use this project is a bit harder than it should be for me, because I have a 12 in, 12 out switcher.  The result is that the rear layout won't work with your board layouts.  Not a big deal, I have a mess of RG59 and RCA compression connectors, so I was just going to make a bunch of RCA jumper wires, otherwise I would have to abandon your board layouts entirely.  I slap a picture on to show what I mean.

I appreciate you humoring me.

Numbski, 2022-07-04:
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

Numbski, 2022-07-04:
Since I was taking pictures, I went ahead and finished painting the RCA jacks on this thing.  Those two broken BNCs are going to bug me, even though they are on outputs 11 and 12, and are likely to never get used.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

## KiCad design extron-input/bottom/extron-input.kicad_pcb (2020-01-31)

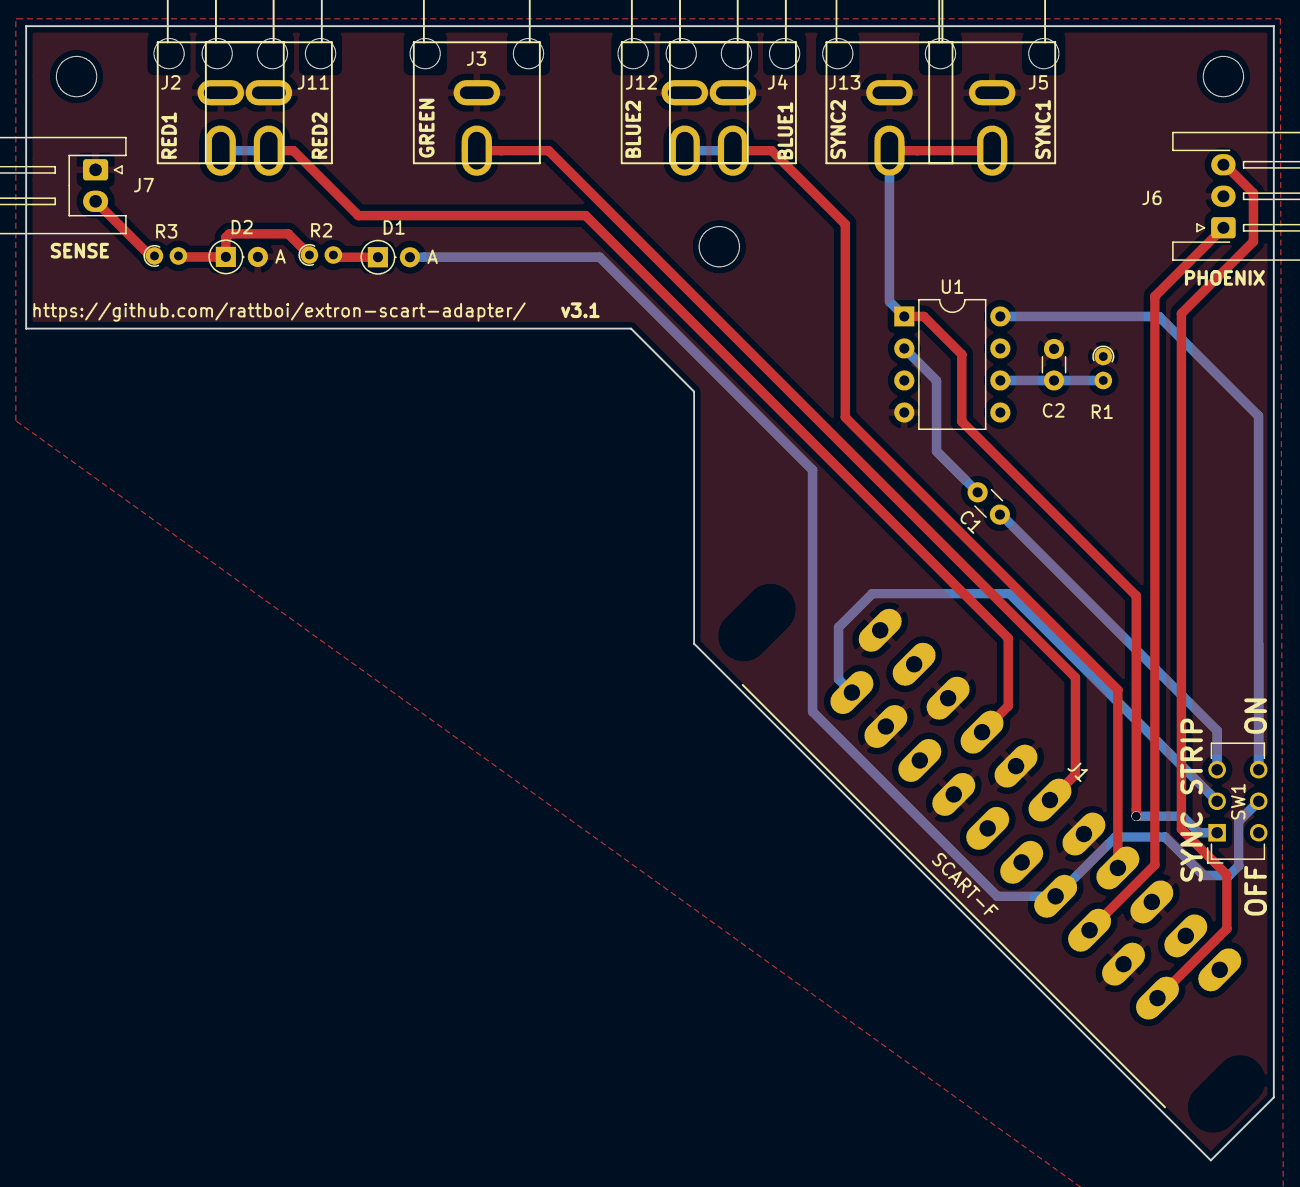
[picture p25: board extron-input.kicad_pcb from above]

Board: 2 copper layers, 99.0 x 90.0 mm, 22 parts (0 on the bottom side), 16 nets.

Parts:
C1, C2: 0.1uF; C_Disc_D3.0mm_W1.6mm_P2.50mm
D1: 1N4148; D_DO-35_SOD27_P2.54mm_Vertical_AnodeUp
D2: 1N4728A; D_DO-35_SOD27_P2.54mm_Vertical_AnodeUp
J1: SCART-F; SCART_F_RA
J2: RED1; rca_combined
J3: GREEN; rca_combined
J4: BLUE1; rca_combined
J5: SYNC1; rca_combined
J6: PHOENIX; JST_XH_S3B-XH-A-1_1x03_P2.50mm_Horizontal
J7: SENSE; JST_XH_S2B-XH-A_1x02_P2.50mm_Horizontal
J8, J9, J10: Conn_01x01; MountingHole_3.2mm_M3
J11: RED2; rca_combined
J12: BLUE2; rca_combined
J13: SYNC2; rca_combined
R1: 680KΩ; R_Axial_DIN0204_L3.6mm_D1.6mm_P1.90mm_Vertical
R2: 100Ω; R_Axial_DIN0204_L3.6mm_D1.6mm_P1.90mm_Vertical
R3: 1KΩ; R_Axial_DIN0204_L3.6mm_D1.6mm_P1.90mm_Vertical
SW1: SW_DPDT_x2; SW_CuK_JS202011AQN_DPDT_Angled
U1: LM1881; DIP-8_W7.62mm

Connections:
BLUE: J1.7, J4.2, J12.2
GND: C2.2, D2.2, J1.4, J1.5, J1.9, J1.13, J1.14, J1.17, J1.18, J1.21, J2.1, J3.1, J4.1, J5.1, J6.2, J7.1, J11.1, J12.1, J13.1, R1.1, U1.4
GREEN: J1.11, J3.2
unnamed: C1.1, SW1.3
unnamed: C1.2, U1.2
unnamed: C2.1, R1.2, U1.6
unnamed: D1.1, R2.2
unnamed: D2.1, R2.1, R3.2
unnamed: J1.2, J6.3
unnamed: J1.6, J6.1
unnamed: J1.20, SW1.2
unnamed: J7.2, R3.1
unnamed: SW1.6, U1.8
RED: J1.15, J2.2, J11.2
SENSE: D1.2, J1.8, SW1.5
SYNC: J5.2, J13.2, SW1.1, U1.1

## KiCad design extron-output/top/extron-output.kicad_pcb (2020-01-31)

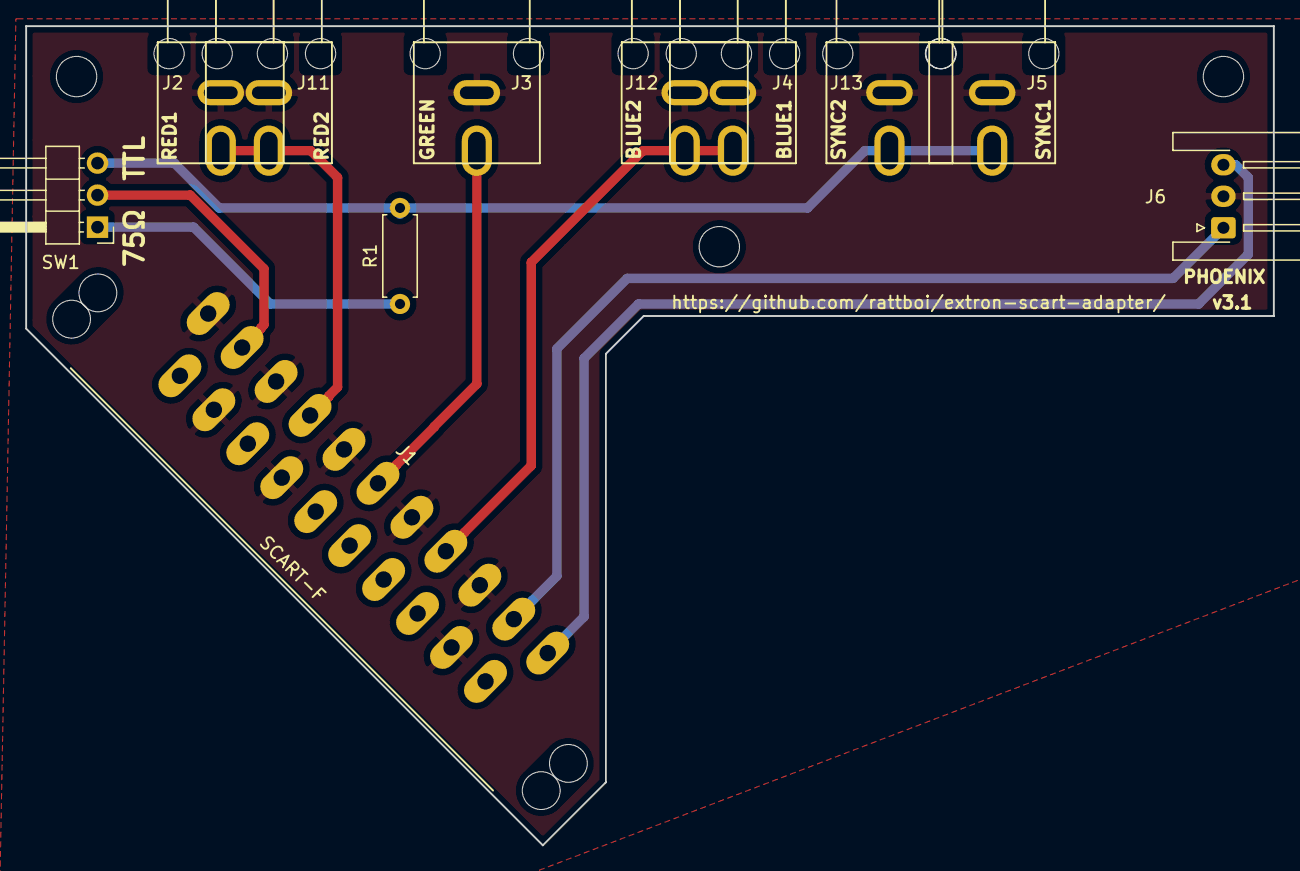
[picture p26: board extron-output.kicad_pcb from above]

Board: 2 copper layers, 99.0 x 65.0 mm, 14 parts (0 on the bottom side), 9 nets.

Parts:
J1: SCART-F; SCART_F_RA
J2: RED1; rca_combined
J3: GREEN; rca_combined
J4: BLUE1; rca_combined
J5: SYNC1; rca_combined
J6: PHOENIX; JST_XH_S3B-XH-A-1_1x03_P2.50mm_Horizontal
J8, J9, J10: Conn_01x01; MountingHole_3.2mm_M3
J11: RED2; rca_combined
J12: BLUE2; rca_combined
J13: SYNC2; rca_combined
R1: 470; R_Axial_DIN0207_L6.3mm_D2.5mm_P7.62mm_Horizontal
SW1: SW_SPDT; PinHeader_1x03_P2.54mm_Horizontal

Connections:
BLUE: J1.7, J4.2, J12.2
GND: J1.4, J1.5, J1.9, J1.13, J1.14, J1.17, J1.18, J1.21, J2.1, J3.1, J4.1, J5.1, J6.2, J11.1, J12.1, J13.1
GREEN: J1.11, J3.2
unnamed: J1.1, J6.3
unnamed: J1.3, J6.1
unnamed: J1.19, SW1.2
unnamed: R1.1, SW1.1
RED: J1.15, J2.2, J11.2
SYNC: J5.2, J13.2, R1.2, SW1.3

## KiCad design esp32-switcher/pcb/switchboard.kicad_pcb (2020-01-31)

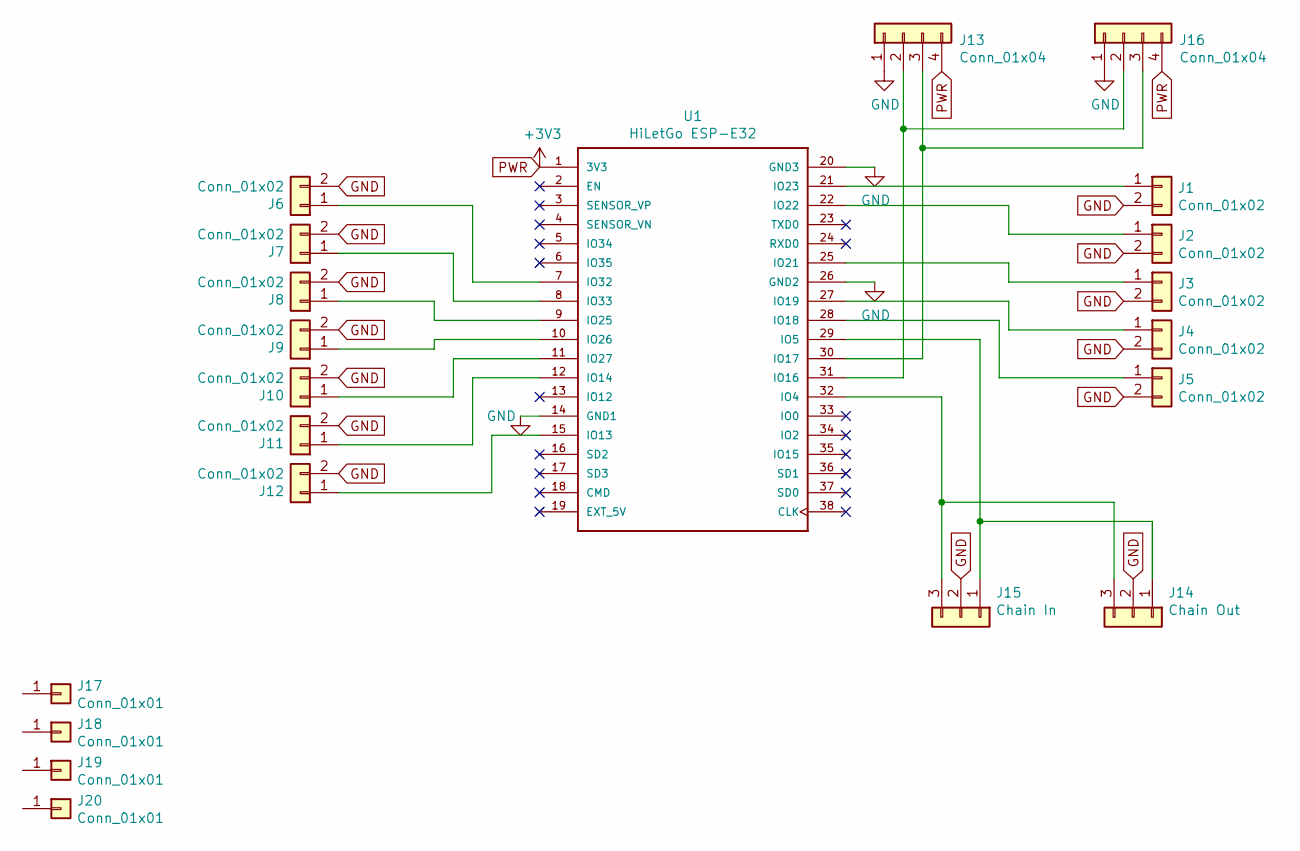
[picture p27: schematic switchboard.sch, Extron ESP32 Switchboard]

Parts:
J1, J2, J3, J4, J5, J6, J7, J8, J9, J10, J11, J12: Conn_01x02; JST_XH_B2B-XH-AM_1x02_P2.50mm_Vertical
J13, J16: Conn_01x04; PinSocket_1x04_P2.54mm_Vertical
J14: Chain Out; JST_XH_B3B-XH-AM_1x03_P2.50mm_Vertical
J15: Chain In; JST_XH_B3B-XH-AM_1x03_P2.50mm_Vertical
J17, J18, J19, J20: Conn_01x01; MountingHole_3.2mm_M3
U1: HiLetGo ESP-E32; HILETGO-E32

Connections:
GND: J1.2, J2.2, J3.2, J4.2, J5.2, J6.2, J7.2, J8.2, J9.2, J10.2, J11.2, J12.2, J13.1, J14.2, J15.2, J16.1, U1.14 (GND1), U1.20 (GND3), U1.26 (GND2)
unnamed: J1.1, U1.21 (IO23)
unnamed: J2.1, U1.22 (IO22)
unnamed: J3.1, U1.25 (IO21)
unnamed: J4.1, U1.27 (IO19)
unnamed: J5.1, U1.28 (IO18)
unnamed: J6.1, U1.7 (IO32)
unnamed: J7.1, U1.8 (IO33)
unnamed: J8.1, U1.9 (IO25)
unnamed: J9.1, U1.10 (IO26)
unnamed: J10.1, U1.11 (IO27)
unnamed: J11.1, U1.12 (IO14)
unnamed: J12.1, U1.15 (IO13)
unnamed: J13.2, J16.2, U1.31 (IO16)
unnamed: J13.3, J16.3, U1.30 (IO17)
unnamed: J14.1, J15.1, U1.29 (IO5)
unnamed: J14.3, J15.3, U1.32 (IO4)
PWR: J13.4, J16.4, U1.1 (3V3)

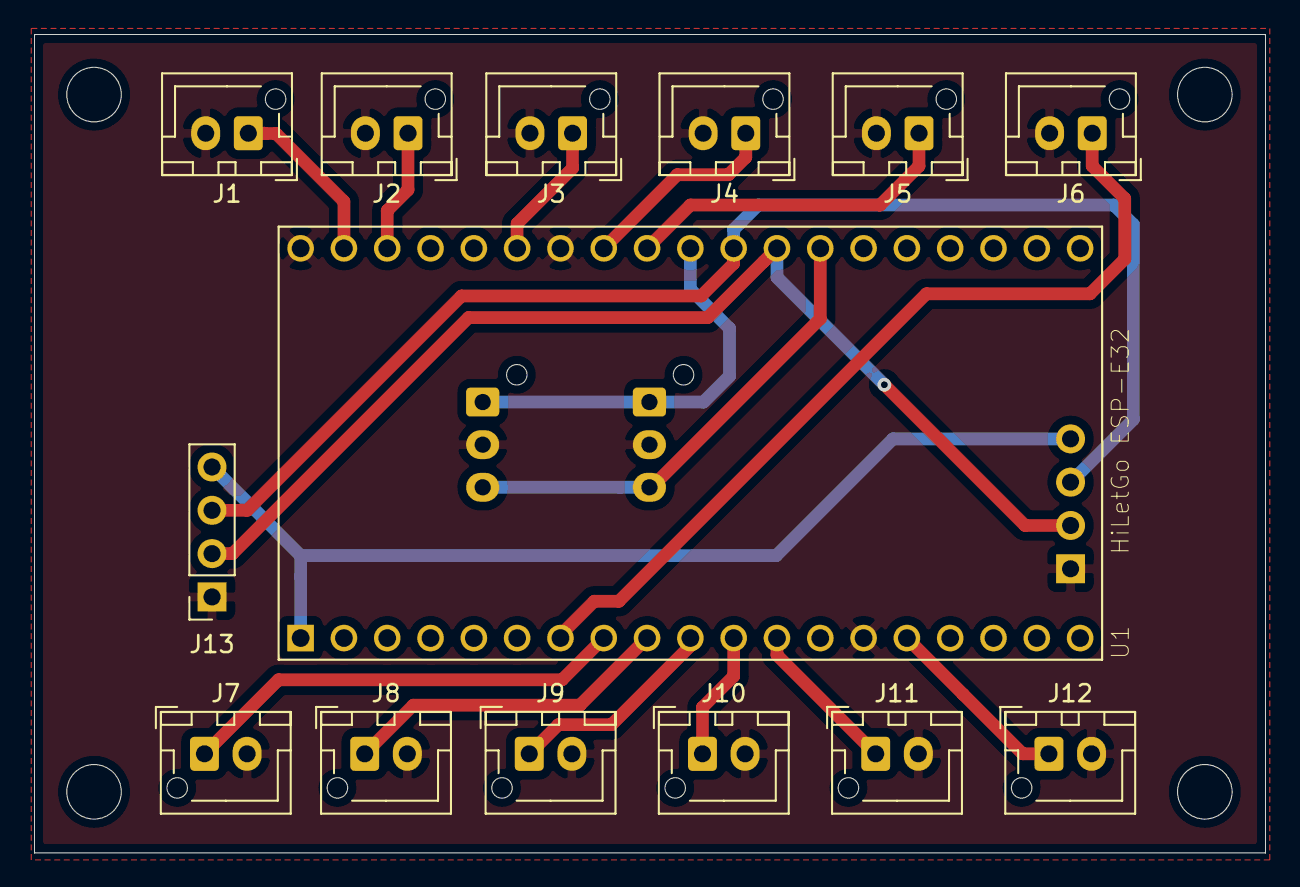
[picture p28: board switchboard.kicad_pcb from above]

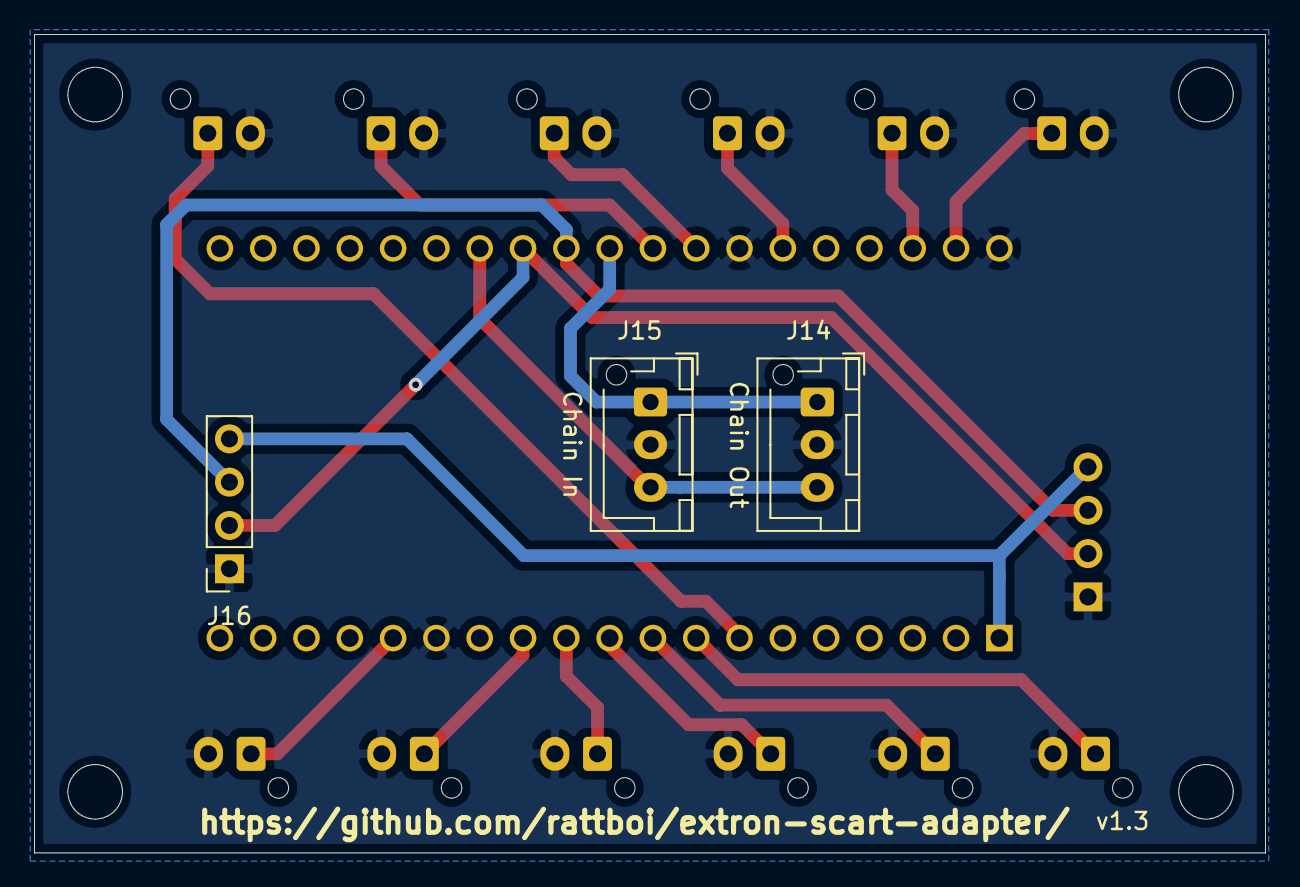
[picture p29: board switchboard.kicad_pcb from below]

Board: 2 copper layers, 72.2 x 48.0 mm, 21 parts (3 on the bottom side), 18 nets.

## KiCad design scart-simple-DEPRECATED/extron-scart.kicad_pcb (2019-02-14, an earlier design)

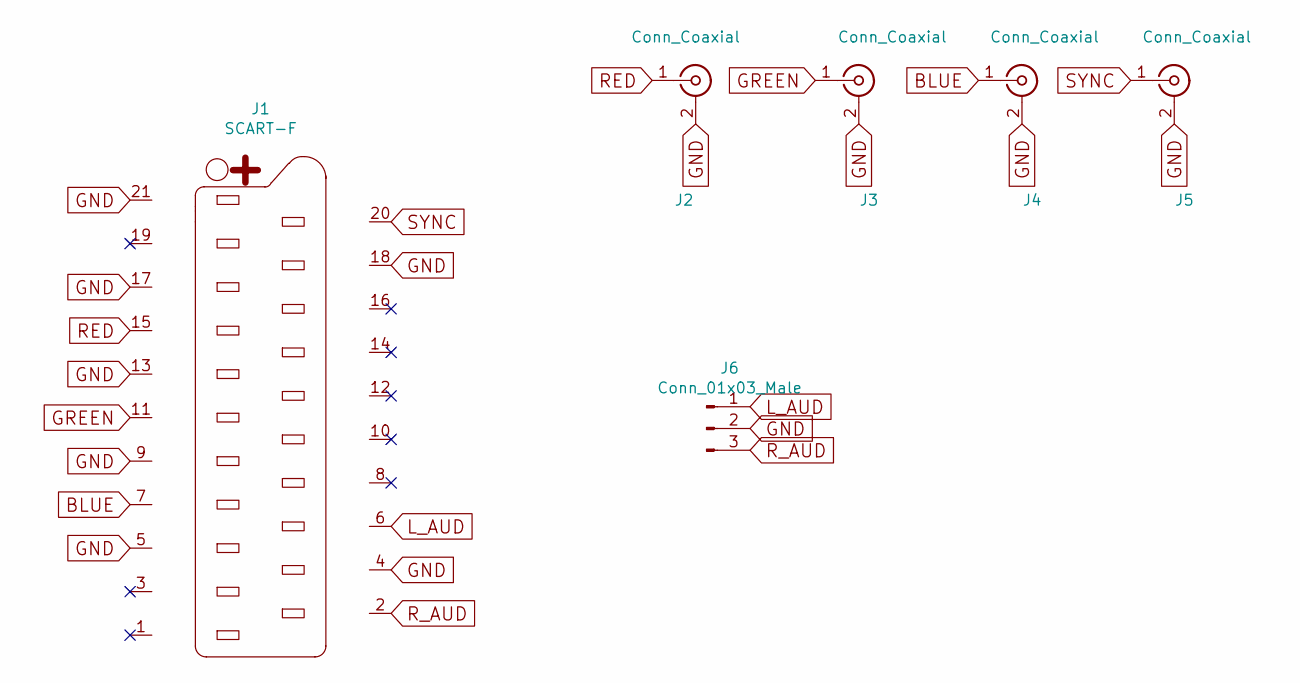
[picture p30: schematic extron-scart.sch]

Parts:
J1: SCART-F; SCART_F
J2, J3, J4, J5: Conn_Coaxial; RCA
J6: Conn_01x03_Male; PinHeader_1x03_P2.54mm_Vertical

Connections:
BLUE: J1.7, J4.1 (In)
GND: J1.4, J1.5, J1.9, J1.13, J1.17, J1.18, J1.21, J2.2 (Ext), J3.2 (Ext), J4.2 (Ext), J5.2 (Ext), J6.2
GREEN: J1.11, J3.1 (In)
L_AUD: J1.6, J6.1
RED: J1.15, J2.1 (In)
R_AUD: J1.2, J6.3
SYNC: J1.20, J5.1 (In)

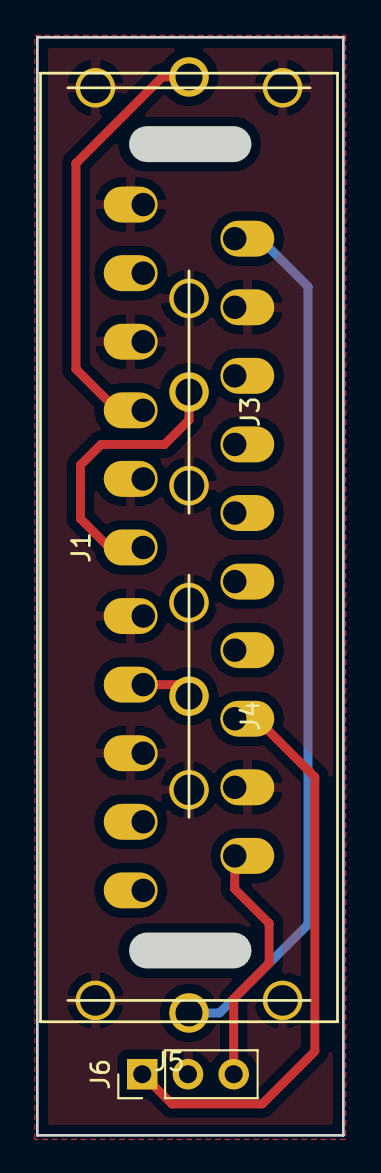
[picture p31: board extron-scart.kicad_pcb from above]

Board: 2 copper layers, 17.0 x 61.0 mm, 6 parts (0 on the bottom side), 7 nets.

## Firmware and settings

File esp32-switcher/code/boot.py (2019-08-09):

import gc

from machine import UART
from machine import Pin
from machine import Timer

uart = UART(2, 9600)
uart.init(9600, bits=8, parity=None, stop=1)

input_pins = [23, 22, 21, 19, 18, 32, 33, 25, 26, 27, 14, 13]
pins = [Pin(i, Pin.IN, Pin.PULL_DOWN) for i in input_pins]
off_buffer = [0 for i in input_pins]
off_buffer_timer = Timer(-1)

outputs = [1, 4]

def set_to_zero(ref, idx):
    ref[idx] = 0

def pin_callback(pin):
    gc.collect()  # Seems like a decent time to force a clean up...

    input_idx = pins.index(pin)

    # Seems that inputs bounce on console off, so let's debounce with a timer
    if pin() == 0:
        off_buffer[input_idx] = 1
        off_buffer_timer.init(period=100, mode=Timer.ONE_SHOT, callback=lambda t: set_to_zero(off_buffer, input_idx))
    else:
        if off_buffer[input_idx] == 0: # if you're not a bouncing input, then switch
            for output in outputs:
                serial_write = '{}*{}!'.format(input_idx + 1, output)
                uart.write(serial_write)
                print(serial_write)
        else: # this is a bouncing input that recently turned off, don't switch
            print('input {} bounced...'.format(input_idx + 1))

irqs = [pin.irq(handler=pin_callback, trigger=Pin.IRQ_RISING | Pin.IRQ_FALLING) for pin in pins]

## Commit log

2019-02-14 First test. Sent off to OSHPark.
    Based off Arithmaldor's SCART-to-RCA project. Thanks, buddy.
    [extron-scart.kicad_pcb, extron-scart.sch]
2019-02-27 New sch/pcb input from extron crosspoint dimensions
    Different orientation for the board
    Added selectable sync stripper
    Missing mounting holes, and better silkscreen, but mostly done
    [extron-scart.kicad_pcb, extron-scart.sch]
2019-02-27 Remove unused schematic libs
2019-02-27 V1.0 -> Sent to JLCPCB
    Hopefully everything is right
    [extron-scart.kicad_pcb, extron-scart.sch]
2019-02-27 Move to subdir, make fakey readme
    [extron-scart.kicad_pcb, extron-scart.sch]
2019-02-27 Move old proj to scart-simple (deprecated)
    [extron-scart.kicad_pcb, extron-scart.sch]
2019-02-27 Attempt to table-ize the bom
2019-02-27 Trying to make the BOM more readable
2019-02-28 Add 3d renders for input board
2019-02-28 Remove gerbers zip
2019-02-28 Oops, scart-input -> extron-input
    [extron-input.kicad_pcb, extron-input.sch]
2019-02-28 Make sure that it's obvious the simple-scart deprecated
    [extron-scart.kicad_pcb, extron-scart.sch]
2019-02-28 Add new Extron Output board. Need to fix readme to reflect
    [extron-output.kicad_pcb, extron-output.sch]
2019-02-28 Fix resistor value in BOM for input adapter
2019-02-28 Random fixes to extron-input layout/schematic
    There were some weirdnesses between the schematic and layout. I believe
    these are fixed now.
    I also switched the footprint to JST XH side connectors for both sense
    and phoenix ports. I found that there are cables that can be purchased
    for cheap for this form factor.
    [extron-input.kicad_pcb, extron-input.sch]
2019-02-28 Forgot to reflow the ground planes after making adjustments
    [extron-output.kicad_pcb]
2019-02-28 Update BOM with XH side connectors
2019-03-10 Rev 2 input board (+ other small things)
    BNC F -> RCA F for all outputs to extron
    The BNC is great, but expensive, and also impossible to close over an
    extron input when they are matrixed. The RCA female recepticles will
    all to use with RCA M -> BNC M adapters, which you can pre-load onto
    the extron BNC F inputs. This will allow cards to plug in
    individually, or all at once if you have a stack of cards held
    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
    [extron-input.kicad_pcb, extron-input.sch]
2019-03-10 Update readme to show out-of-date, rca too thicc
    [extron-input.kicad_pcb]
2019-03-10 Redo renders, fix RCA 3d model reference
    [extron-input.kicad_pcb]
2019-03-10 Added vendor/link to all schematic parts
    [extron-input.sch]
2019-03-10 Updated BOM in input card readme
2019-03-10 More BOM fixes
2019-03-28 Rev 2.1
    Fixed up rca problems by making combined footprint for the two different
    CUI-style connectors.
    Shifted scart over so it doesn't run into standoffs (hopefully)
    Fixed resistor value in sense circuit
    Reversed stereo audio signals
    Added logos + link to site
    [extron-input.kicad_pcb, extron-input.sch]
2019-03-28 Added new pcb renders (2d, at least)
2019-04-01 WIP esp32-switchboard + esp32 micropython code
    [switchboard.kicad_pcb, switchboard.sch]
2019-04-01 Updates, almost ready to go
    [switchboard.kicad_pcb, switchboard.sch]
2019-04-05 Rev 1.1 of ESP32 Switchboard
    I think this rev is basically ready to go. I could see someone using
    this for real. I still have a lot of software features I wanna add, but
    the hardware is basically complete.
    I may come back and add a built-in serial port, as the little breakout
    can be flimsy, but it seems that 3v3 rs232 stuff means SMD components,
    and I've been trying to avoid that to make this easier to DIY.
    board:
    Converted footprint to Kicad non-legacy
    Fixed footprint to be HiLetGo ESP-E32, which is narrower than NodeMCU
    Fixed up references on schematic to be in order
    Flipped mistaken footprint on RS232 UART breakout
    code:
    Added support for all 12 inputs
    IRQ-based on rising/f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
    [switchboard.kicad_pcb, switchboard.sch]
2019-04-05 Rearranged files, updated docs. Hopefully ready to merge
    [switchboard.kicad_pcb, switchboard.sch]
2019-04-05 Fix switchboard renders
2019-04-13 Update extron output board to use combined RCA (v2.1)
    Small fixes for extron input as well (v2.1)
    [extron-input.kicad_pcb, extron-input.sch, extron-output.kicad_pcb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]
2019-04-13 Switchboard v1.2
    Switch around all the XA connectors to allow for either top-entry or
    side-entry XH connectors.
    [switchboard.kicad_pcb, switchboard.sch]
2019-04-15 Add mounting holes and 2nd position for serial uart on switchboard
    Also, "rescue" components on scart-input board. I gotta figure out what
    that's about...
    [extron-input.sch, switchboard.kicad_pcb, switchboard.sch]
2019-05-22 Version 2.2 of extron input (move sense to top)
    This revision moves the sense circuit to the top of the board, which
    makes the audio plug a lot easier to get at, and you can throw your
    esp32-switcher on the top of your extron.
    Also cleaned up rescue files for eeschema. Come on, eeschema. Get your
    shit together.
    [extron-input.kicad_pcb, extron-input.sch]
2019-05-22 Fixup references from schematic -> pcb
    [extron-input.kicad_pcb]
2019-08-04 Version 3.1 (#6)
    * WIP on input board v3
    New features:
    Longer boards that support top/bottom placement, allowing closer
    placement for extron 300 ADSP models, and allowing thicker FR4 again
    Will have new RCA placements to support both older and newer extron
    BNC spacings
    * WIP v3 (more)
    * Made separate top/bottom directories (only top for now)
    * Made symlinks to keep one schematic for two pcbs
    * Modified "rca_combined" to no longer be combined. We're going w/ the rca
    boom from lcsc.
    * Doubled up footprints for R / B / Sync to support both new and old
    extron crosspoints
    * Added bottom board
    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
    [extron-input.kicad_pcb, extron-input.sch, extron-output.kicad_pcb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]
2019-08-09 Update renders for autoswitch board
    Add multi-output (still hardcoded, but it's a start)
    Naming refactors
    [switchboard.kicad_pcb]
2019-09-19 Adding BOM for Switchboard
2020-01-31 Fix errors about KiCad version (#8)
    I was using a nightly build of Kicad and some of those changes didn't
    end up making it into the main release. Now you should be able to just
    get latest Kicad and open all the files.
    [extron-input.kicad_pcb, extron-output.kicad_pcb, switchboard.kicad_pcb]
2021-09-07 Fix R2 in BOM
    Was right in the schematic, but missed updating the bom :(
